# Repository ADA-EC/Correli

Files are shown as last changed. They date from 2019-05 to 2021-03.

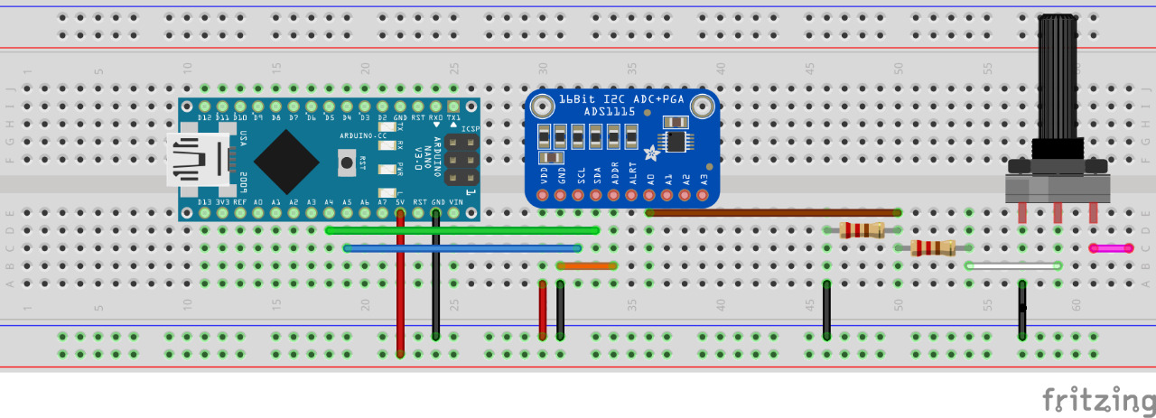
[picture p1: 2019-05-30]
Conversor AD/Esquemático ADC.jpeg

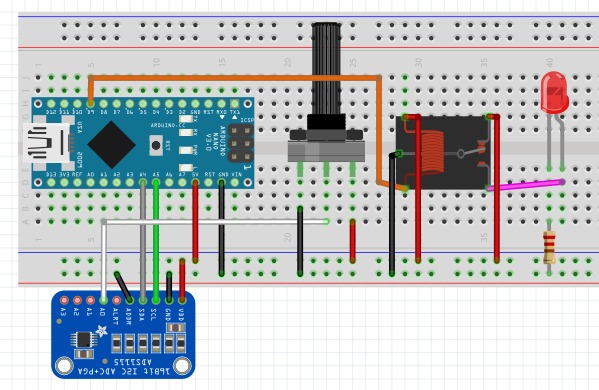
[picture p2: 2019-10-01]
Esquematico/esquematico_nano.jpeg

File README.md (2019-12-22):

# Projeto Correli
Projeto desenvolvido pelo Grupo ADA - Projetos em Engenharia de Computação em parceiria com o Departamento de Estruturas da EESC - USP.

## Configuração
É necessário que um Arduino esteja conectado a uma porta USB do computador para que o código seja executado corretamente.

### Ubuntu
Antes de executar o código no sistesma operacional Ubuntu (os testes foram realizados no Ubuntu 18.04), é necessário possuir o [Python versão 3](https://www.python.org/download/releases/3.0/), e instalar as seguintes bibliotecas:

- [tkinter](https://docs.python.org/3/library/tkinter.html)
- [pyserial](https://pyserial.readthedocs.io/en/latest/pyserial.html) 
- [serial.tools.list_ports](https://pyserial.readthedocs.io/en/latest/tools.html)

Para rodar o código, digitar o seguinte comando no terminal:
   
   `$ python3 interface.py`
 
### Windows
No WIndows, basta rodar o executável previamente criado com Pyinstaller que o programa será executado normalmente. Para executar o código a partir do aquivo Python, é necessário possuir as mesmas bibliotecas e versão do Python exigida para execução em Linux e clicar duas vezes no programa para executá-lo.

## Descrição do Projeto
Criação de um sistema que integre uma prensa hidráulica e uma câmera que tira fotos do corpo de prova que é submetido ao ensaio na prensa. Por meio de uma interface gráfica, o usuário escolhe o modo de operação da camêra (por tempo ou por intervalo de força realizado pela prensa) para tirar a foto. Os dados do ensaio e as tensões nos momentos em que as fotos s
ão tiradas são registrados em um arquivo que fica salvo no final da execução. 

### Prensa Hidráulica
A prensa possui uma saída de tensão que pode ser relacionada com a força que está sendo aplicada em um corpo de prova. Essa tensão pode variar entre -10 volts e 10 volts, a princípio iremos considerar apenas os valores positivos (0-10 volts), tendo uma precisão de 4 casas decimais na leitura dessa tensão e, por fim, podemos convertê-la para força, uma vez que a cada volt temos 25 toneladas sendo aplicado. 

### Câmera
Já a câmera (Canon EOS 30D), possui um função de acionamento remoto, com isso, podemos tirar uma foto sem necessariamente pressionarmos o botão. A ideia do projeto é integrar as fotos tiradas com a força que está sendo aplicada naquele momento e criar um arquivo “.txt”  contendo essa informações. O acionamento da câmera pode ser regulado tanto pelo tempo, tirando fotos em certos intervalos de tempo, quanto por certo intervalos de forças.

### Interface Gráfica
A interface gráfica foi feita em Python. Ela permite que o usuário crie um arquivo com o nome escolhido por ele, escolha a forma de acionamento da câmera (por tempo ou pressão) e defina o intervalo que seja mais conveniente a ele. Então é iniciado o programa, ele se conecta com o código criado para o Arduino Nano e, então, aparece na tela os valores obtidos da pressão que a prensa hidráulica exerce no exato momento em que a foto é tirada. Para utiliza-lá é preciso que o usuário possua tanto o [Python](https://www.python.org/download/releases/3.0/) quanto a biblioteca [PySerial](https://github.com/pyserial/pyserial) instaladas. 

### Prototipagens
O esquemático apresenta o circuito com Arduino, Relé e conversor AD de maneira que seja possível o acionamento da câmera em intervalos especificados pelo usuário de tempo ou tensão.
Simulou-se a prensa para que fosse possível realizar alguns testes. Para isso, utilizou-se 2 potenciômetros conectados, em que um limita a tensão recebida pela fonte (que é de 12V) em até 10V e o segundo simula as tensões que seriam enviadas pela prensa hidráulica.
A câmera é conectada nos terminais do relé indicados no esquemático. Ela tira fotos quando o circuito é fechado pelo relé, em intervalos de tempo ou tensão definidos pelo código.
Imagem do primeiro esquemático

No segundo modelo feito, utilizou-se um Arduino Nano ao invés do Uno. Também não foi necessário utilizar 2 potenciômetros para simular a prensa, apenas 1. Abaixo está o esquemático do segundo modelo.
Imagem do segundo esquemático

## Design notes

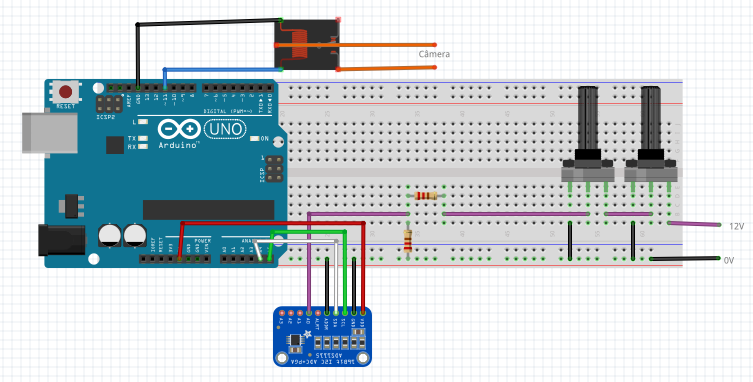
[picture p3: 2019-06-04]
Esquematico/esquematico.png

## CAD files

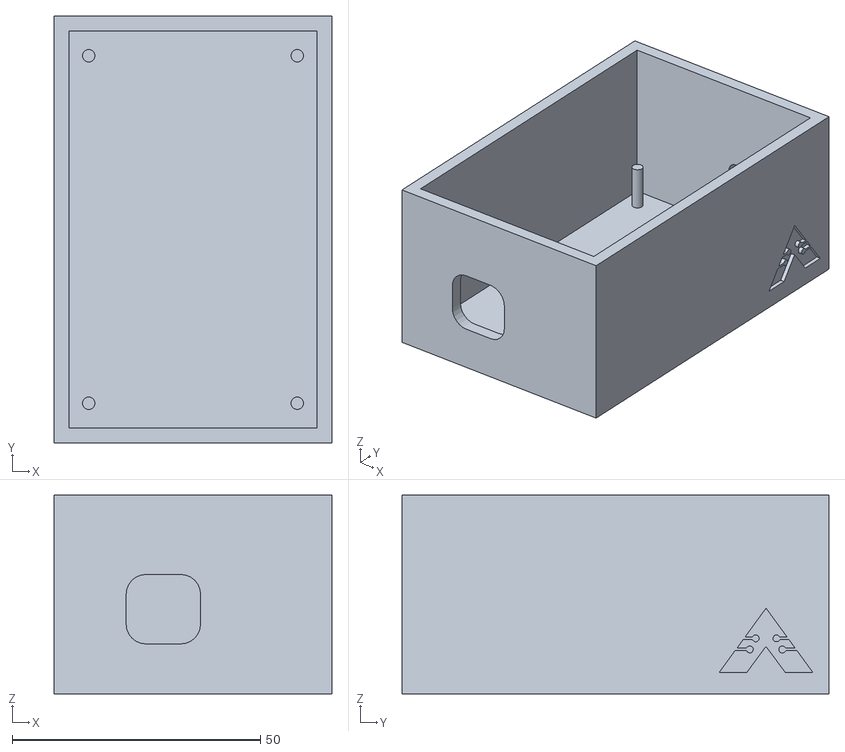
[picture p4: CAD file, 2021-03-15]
Caixa 3D/parede fina.obj
56.0 x 86.0 x 40.0

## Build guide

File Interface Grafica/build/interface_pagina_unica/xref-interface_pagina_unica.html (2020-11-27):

# modulegraph cross reference for interface_pagina_unica.py, pyi_rth__tkinter.py, pyi_rth_multiprocessing.py

interface_pagina_unica.py Script

imports: _bootlocale • _collections_abc • _weakrefset • abc • codecs • collections • collections.abc • copyreg • datetime • encodings • encodings.aliases • encodings.ascii • encodings.base64_codec • encodings.big5 • encodings.big5hkscs • encodings.bz2_codec • encodings.charmap • encodings.cp037 • encodings.cp1006 • encodings.cp1026 • encodings.cp1125 • encodings.cp1140 • encodings.cp1250 • encodings.cp1251 • encodings.cp1252 • encodings.cp1253 • encodings.cp1254 • encodings.cp1255 • encodings.cp1256 • encodings.cp1257 • encodings.cp1258 • encodings.cp273 • encodings.cp424 • encodings.cp437 • encodings.cp500 • encodings.cp720 • encodings.cp737 • encodings.cp775 • encodings.cp850 • encodings.cp852 • encodings.cp855 • encodings.cp856 • encodings.cp857 • encodings.cp858 • encodings.cp860 • encodings.cp861 • encodings.cp862 • encodings.cp863 • encodings.cp864 • encodings.cp865 • encodings.cp866 • encodings.cp869 • encodings.cp874 • encodings.cp875 • encodings.cp932 • encodings.cp949 • encodings.cp950 • encodings.euc_jis_2004 • encodings.euc_jisx0213 • encodings.euc_jp • encodings.euc_kr • encodings.gb18030 • encodings.gb2312 • encodings.gbk • encodings.hex_codec • encodings.hp_roman8 • encodings.hz • encodings.idna • encodings.iso2022_jp • encodings.iso2022_jp_1 • encodings.iso2022_jp_2 • encodings.iso2022_jp_2004 • encodings.iso2022_jp_3 • encodings.iso2022_jp_ext • encodings.iso2022_kr • encodings.iso8859_1 • encodings.iso8859_10 • encodings.iso8859_11 • encodings.iso8859_13 • encodings.iso8859_14 • encodings.iso8859_15 • encodings.iso8859_16 • encodings.iso8859_2 • encodings.iso8859_3 • encodings.iso8859_4 • encodings.iso8859_5 • encodings.iso8859_6 • encodings.iso8859_7 • encodings.iso8859_8 • encodings.iso8859_9 • encodings.johab • encodings.koi8_r • encodings.koi8_t • encodings.koi8_u • encodings.kz1048 • encodings.latin_1 • encodings.mac_arabic • encodings.mac_croatian • encodings.mac_cyrillic • encodings.mac_farsi • encodings.mac_greek • encodings.mac_iceland • encodings.mac_latin2 • encodings.mac_roman • encodings.mac_romanian • encodings.mac_turkish • encodings.mbcs • encodings.oem • encodings.palmos • encodings.ptcp154 • encodings.punycode • encodings.quopri_codec • encodings.raw_unicode_escape • encodings.rot_13 • encodings.shift_jis • encodings.shift_jis_2004 • encodings.shift_jisx0213 • encodings.tis_620 • encodings.undefined • encodings.unicode_escape • encodings.utf_16 • encodings.utf_16_be • encodings.utf_16_le • encodings.utf_32 • encodings.utf_32_be • encodings.utf_32_le • encodings.utf_7 • encodings.utf_8 • encodings.utf_8_sig • encodings.uu_codec • encodings.zlib_codec • enum • functools • heapq • io • json • keyword • linecache • locale • operator • os • pyi_rth__tkinter.py • pyi_rth_multiprocessing.py • re • reprlib • serial • serial.tools.list_ports • sre_compile • sre_constants • sre_parse • sys • tkinter • tkinter.filedialog • tkinter.messagebox • traceback • types • warnings • weakref

pyi_rth__tkinter.py Script

imports: os • sys

imported by: interface_pagina_unica.py

pyi_rth_multiprocessing.py Script

imports: multiprocessing • multiprocessing.popen_fork • multiprocessing.popen_spawn_posix • multiprocessing.popen_spawn_win32 • multiprocessing.spawn • os • re • subprocess • sys

imported by: interface_pagina_unica.py

'System.IO' MissingModule

imported by: serial.serialcli

'java.lang' MissingModule

imported by: platform • xml.sax._exceptions

'org.python' MissingModule

imported by: copy • xml.sax

System MissingModule

imported by: serial.serialcli

__future__ SourceModule

imported by: codeop • doctest • serial • serial.serialcli • serial.serialjava • serial.serialposix • serial.serialutil • serial.serialwin32 • serial.tools.list_ports • serial.tools.list_ports_common • serial.tools.list_ports_linux • serial.tools.list_ports_osx • serial.tools.list_ports_posix • serial.tools.list_ports_windows • serial.win32

_abc (builtin module)

imported by: abc

_aix_support SourceModule

imports: _bootsubprocess • subprocess • sys • sysconfig

imported by: distutils.util • sysconfig

_ast (builtin module)

imported by: ast

_asyncio c:\program files\python39\DLLs\_asyncio.pyd

imported by: asyncio.events • asyncio.futures • asyncio.tasks

_bisect (builtin module)

imported by: bisect

_blake2 (builtin module)

imported by: hashlib

_bootlocale SourceModule

imports: _locale • locale • sys

imported by: interface_pagina_unica.py • locale

_bootsubprocess SourceModule

imports: os

imported by: _aix_support

_bz2 c:\program files\python39\DLLs\_bz2.pyd

imported by: bz2

_codecs (builtin module)

imported by: codecs

_codecs_cn (builtin module)

imported by: encodings.gb18030 • encodings.gb2312 • encodings.gbk • encodings.hz

_codecs_hk (builtin module)

imported by: encodings.big5hkscs

_codecs_iso2022 (builtin module)

imported by: encodings.iso2022_jp • encodings.iso2022_jp_1 • encodings.iso2022_jp_2 • encodings.iso2022_jp_2004 • encodings.iso2022_jp_3 • encodings.iso2022_jp_ext • encodings.iso2022_kr

_codecs_jp (builtin module)

imported by: encodings.cp932 • encodings.euc_jis_2004 • encodings.euc_jisx0213 • encodings.euc_jp • encodings.shift_jis • encodings.shift_jis_2004 • encodings.shift_jisx0213

_codecs_kr (builtin module)

imported by: encodings.cp949 • encodings.euc_kr • encodings.johab

_codecs_tw (builtin module)

imported by: encodings.big5 • encodings.cp950

_collections (builtin module)

imported by: collections • threading

_collections_abc SourceModule

imports: abc • sys

imported by: collections • collections.abc • contextlib • interface_pagina_unica.py • locale • os • pathlib • random • types • weakref

_compat_pickle SourceModule

imported by: _pickle • pickle

_compression SourceModule

imports: io

imported by: bz2 • gzip • lzma

_contextvars (builtin module)

imported by: contextvars

_csv (builtin module)

imported by: csv

_ctypes c:\program files\python39\DLLs\_ctypes.pyd

imported by: ctypes

_datetime (builtin module)

imports: _strptime • time

imported by: datetime

_decimal c:\program files\python39\DLLs\_decimal.pyd

imported by: decimal

_elementtree c:\program files\python39\DLLs\_elementtree.pyd

imports: pyexpat • xml.etree.ElementInclude • xml.etree.ElementPath • xml.etree.ElementTree • xml.etree.cElementTree

imported by: xml.etree.ElementTree

_frozen_importlib ExcludedModule

imported by: importlib • importlib.abc • zipimport

_frozen_importlib_external MissingModule

imported by: importlib • importlib._bootstrap • importlib.abc • zipimport

_functools (builtin module)

imported by: functools

_hashlib c:\program files\python39\DLLs\_hashlib.pyd

imported by: hashlib • hmac

_heapq (builtin module)

imported by: heapq

_imp (builtin module)

imported by: distutils.sysconfig • importlib • importlib.machinery • importlib.util • zipimport

_io (builtin module)

imported by: io • zipimport

_json (builtin module)

imports: json.decoder

imported by: json.decoder • json.encoder • json.scanner

_locale (builtin module)

imported by: _bootlocale • locale • re

_lzma c:\program files\python39\DLLs\_lzma.pyd

imported by: lzma

_md5 (builtin module)

imported by: hashlib

_multibytecodec (builtin module)

imported by: encodings.big5 • encodings.big5hkscs • encodings.cp932 • encodings.cp949 • encodings.cp950 • encodings.euc_jis_2004 • encodings.euc_jisx0213 • encodings.euc_jp • encodings.euc_kr • encodings.gb18030 • encodings.gb2312 • encodings.gbk • encodings.hz • encodings.iso2022_jp • encodings.iso2022_jp_1 • encodings.iso2022_jp_2 • encodings.iso2022_jp_2004 • encodings.iso2022_jp_3 • encodings.iso2022_jp_ext • encodings.iso2022_kr • encodings.johab • encodings.shift_jis • encodings.shift_jis_2004 • encodings.shift_jisx0213

_multiprocessing c:\program files\python39\DLLs\_multiprocessing.pyd

imported by: multiprocessing.connection • multiprocessing.queues • multiprocessing.resource_tracker • multiprocessing.synchronize

_opcode (builtin module)

imported by: opcode

_operator (builtin module)

imported by: hmac • operator

_osx_support SourceModule

imports: contextlib • distutils • distutils.log • os • re • sys • tempfile

imported by: distutils.sysconfig • distutils.util • sysconfig

_overlapped c:\program files\python39\DLLs\_overlapped.pyd

imported by: asyncio.windows_events

_pickle (builtin module)

imports: _compat_pickle • codecs • copyreg

imported by: pickle

_posixshmem MissingModule

imported by: multiprocessing.resource_tracker • multiprocessing.shared_memory

_posixsubprocess MissingModule

imports: gc

imported by: multiprocessing.util • subprocess

_py_abc SourceModule

imports: _weakrefset

imported by: abc

_pydecimal SourceModule

imports: collections • contextvars • itertools • locale • math • numbers • re • sys

imported by: decimal

_queue c:\program files\python39\DLLs\_queue.pyd

imported by: queue

_random (builtin module)

imported by: random

_scproxy MissingModule

imported by: urllib.request

_sha1 (builtin module)

imported by: hashlib

_sha256 (builtin module)

imported by: hashlib

_sha3 (builtin module)

imported by: hashlib

_sha512 (builtin module)

imported by: hashlib • random

_signal (builtin module)

imported by: signal

_socket c:\program files\python39\DLLs\_socket.pyd

imported by: socket

_sre (builtin module)

imports: copy • re

imported by: sre_compile • sre_constants

_ssl c:\program files\python39\DLLs\_ssl.pyd

imports: socket

imported by: ssl

_stat (builtin module)

imported by: stat

_statistics (builtin module)

imported by: statistics

_string (builtin module)

imported by: string

_strptime SourceModule

imports: _thread • calendar • datetime • locale • re • time

imported by: _datetime • datetime • time

_struct (builtin module)

imported by: struct

_thread (builtin module)

imported by: _strptime • functools • reprlib • tempfile • test.support • threading

_threading_local SourceModule

imports: contextlib • threading • weakref

imported by: threading

_tkinter c:\program files\python39\DLLs\_tkinter.pyd

imported by: tkinter

_tracemalloc (builtin module)

imported by: tracemalloc

_warnings (builtin module)

imported by: warnings

_weakref (builtin module)

imported by: _weakrefset • collections • weakref • xml.sax.expatreader

_weakrefset SourceModule

imports: _weakref • types

imported by: _py_abc • interface_pagina_unica.py • multiprocessing.process • threading • weakref

_winapi (builtin module)

imported by: asyncio.windows_events • asyncio.windows_utils • encodings • multiprocessing.connection • multiprocessing.heap • multiprocessing.popen_spawn_win32 • multiprocessing.reduction • multiprocessing.shared_memory • multiprocessing.spawn • subprocess • test.support

_winreg MissingModule

imported by: platform

abc SourceModule

imports: _abc • _py_abc

imported by: _collections_abc • contextlib • email._policybase • functools • importlib.abc • importlib.metadata • inspect • interface_pagina_unica.py • io • multiprocessing.reduction • numbers • os • selectors • typing

argparse SourceModule

imports: copy • gettext • os • re • shutil • sys • textwrap • warnings

imported by: ast • calendar • code • dis • doctest • gzip • http.server • inspect • serial.tools.list_ports • tarfile • tokenize • unittest.main • zipfile

array (builtin module)

imported by: multiprocessing.dummy • multiprocessing.managers • multiprocessing.reduction • serial.serialposix • serial.serialutil • socket

ast SourceModule

imports: _ast • argparse • collections • contextlib • enum • inspect • sys • warnings

imported by: inspect

asyncio Package

imports: asyncio • asyncio.DefaultEventLoopPolicy • asyncio.base_events • asyncio.base_futures • asyncio.base_subprocess • asyncio.base_tasks • asyncio.constants • asyncio.coroutines • asyncio.events • asyncio.exceptions • asyncio.format_helpers • asyncio.futures • asyncio.locks • asyncio.proactor_events • asyncio.protocols • asyncio.queues • asyncio.runners • asyncio.selector_events • asyncio.sslproto • asyncio.staggered • asyncio.streams • asyncio.subprocess • asyncio.tasks • asyncio.threads • asyncio.transports • asyncio.trsock • asyncio.unix_events • asyncio.windows_events • asyncio.windows_utils • sys

imported by: asyncio • asyncio.base_events • asyncio.base_futures • asyncio.base_subprocess • asyncio.base_tasks • asyncio.constants • asyncio.coroutines • asyncio.events • asyncio.exceptions • asyncio.format_helpers • asyncio.futures • asyncio.locks • asyncio.log • asyncio.proactor_events • asyncio.protocols • asyncio.queues • asyncio.runners • asyncio.selector_events • asyncio.sslproto • asyncio.staggered • asyncio.streams • asyncio.subprocess • asyncio.tasks • asyncio.threads • asyncio.transports • asyncio.trsock • asyncio.unix_events • asyncio.windows_events • asyncio.windows_utils • unittest.async_case

asyncio.DefaultEventLoopPolicy MissingModule

imported by: asyncio • asyncio.events

asyncio.base_events SourceModule

imports: asyncio • asyncio.constants • asyncio.coroutines • asyncio.events • asyncio.exceptions • asyncio.futures • asyncio.log • asyncio.protocols • asyncio.sslproto • asyncio.staggered • asyncio.tasks • asyncio.transports • asyncio.trsock • collections • collections.abc • concurrent.futures • functools • heapq • itertools • os • socket • ssl • stat • subprocess • sys • threading • time • traceback • warnings • weakref

imported by: asyncio • asyncio.proactor_events • asyncio.selector_events • asyncio.unix_events

asyncio.base_futures SourceModule

imports: asyncio • asyncio.format_helpers • reprlib

imported by: asyncio • asyncio.base_tasks • asyncio.coroutines • asyncio.futures

asyncio.base_subprocess SourceModule

imports: asyncio • asyncio.log • asyncio.protocols • asyncio.transports • collections • subprocess • warnings

imported by: asyncio • asyncio.unix_events • asyncio.windows_events

asyncio.base_tasks SourceModule

imports: asyncio • asyncio.base_futures • asyncio.coroutines • linecache • traceback

imported by: asyncio • asyncio.tasks

asyncio.constants SourceModule

imports: asyncio • enum

imported by: asyncio • asyncio.base_events • asyncio.coroutines • asyncio.format_helpers • asyncio.proactor_events • asyncio.selector_events • asyncio.sslproto • asyncio.unix_events

asyncio.coroutines SourceModule

imports: asyncio • asyncio.base_futures • asyncio.constants • asyncio.format_helpers • asyncio.log • collections.abc • functools • inspect • os • sys • traceback • types • warnings

imported by: asyncio • asyncio.base_events • asyncio.base_tasks • asyncio.runners • asyncio.streams • asyncio.tasks • asyncio.unix_events

asyncio.events SourceModule

imports: _asyncio • asyncio • asyncio.DefaultEventLoopPolicy • asyncio.format_helpers • contextvars • os • socket • subprocess • sys • threading

imported by: asyncio • asyncio.base_events • asyncio.futures • asyncio.locks • asyncio.queues • asyncio.runners • asyncio.selector_events • asyncio.staggered • asyncio.streams • asyncio.subprocess • asyncio.tasks • asyncio.threads • asyncio.unix_events • asyncio.windows_events • test.support

asyncio.exceptions SourceModule

imports: asyncio

imported by: asyncio • asyncio.base_events • asyncio.futures • asyncio.locks • asyncio.proactor_events • asyncio.staggered • asyncio.streams • asyncio.tasks • asyncio.unix_events • asyncio.windows_events

asyncio.format_helpers SourceModule

imports: asyncio • asyncio.constants • functools • inspect • reprlib • sys • traceback

imported by: asyncio • asyncio.base_futures • asyncio.coroutines • asyncio.events • asyncio.futures • asyncio.streams

asyncio.futures SourceModule

imports: _asyncio • asyncio • asyncio.base_futures • asyncio.events • asyncio.exceptions • asyncio.format_helpers • concurrent.futures • contextvars • logging • sys

imported by: asyncio • asyncio.base_events • asyncio.proactor_events • asyncio.selector_events • asyncio.tasks • asyncio.unix_events • asyncio.windows_events

asyncio.locks SourceModule

imports: asyncio • asyncio.events • asyncio.exceptions • collections • warnings

imported by: asyncio • asyncio.queues • asyncio.staggered

asyncio.log SourceModule

imports: asyncio • logging

imported by: asyncio.base_events • asyncio.base_subprocess • asyncio.coroutines • asyncio.proactor_events • asyncio.selector_events • asyncio.sslproto • asyncio.streams • asyncio.subprocess • asyncio.unix_events • asyncio.windows_events

asyncio.proactor_events SourceModule

imports: asyncio • asyncio.base_events • asyncio.constants • asyncio.exceptions • asyncio.futures • asyncio.log • asyncio.protocols • asyncio.sslproto • asyncio.transports • asyncio.trsock • collections • io • os • signal • socket • threading • warnings

imported by: asyncio • asyncio.windows_events

asyncio.protocols SourceModule

imports: asyncio

imported by: asyncio • asyncio.base_events • asyncio.base_subprocess • asyncio.proactor_events • asyncio.selector_events • asyncio.sslproto • asyncio.streams • asyncio.subprocess

asyncio.queues SourceModule

imports: asyncio • asyncio.events • asyncio.locks • collections • heapq • warnings

imported by: asyncio • asyncio.tasks

asyncio.runners SourceModule

imports: asyncio • asyncio.coroutines • asyncio.events • asyncio.tasks

imported by: asyncio

asyncio.selector_events SourceModule

imports: asyncio • asyncio.base_events • asyncio.constants • asyncio.events • asyncio.futures • asyncio.log • asyncio.protocols • asyncio.sslproto • asyncio.transports • asyncio.trsock • collections • errno • functools • selectors • socket • ssl • warnings • weakref

imported by: asyncio • asyncio.unix_events • asyncio.windows_events

asyncio.sslproto SourceModule

imports: asyncio • asyncio.constants • asyncio.log • asyncio.protocols • asyncio.transports • collections • ssl • warnings

imported by: asyncio • asyncio.base_events • asyncio.proactor_events • asyncio.selector_events

asyncio.staggered SourceModule

imports: asyncio • asyncio.events • asyncio.exceptions • asyncio.locks • asyncio.tasks • contextlib • typing

imported by: asyncio • asyncio.base_events

asyncio.streams SourceModule

imports: asyncio • asyncio.coroutines • asyncio.events • asyncio.exceptions • asyncio.format_helpers • asyncio.log • asyncio.protocols • asyncio.tasks • socket • sys • warnings • weakref

imported by: asyncio • asyncio.subprocess

asyncio.subprocess SourceModule

imports: asyncio • asyncio.events • asyncio.log • asyncio.protocols • asyncio.streams • asyncio.tasks • subprocess • warnings

imported by: asyncio

asyncio.tasks SourceModule

imports: _asyncio • asyncio • asyncio.base_tasks • asyncio.coroutines • asyncio.events • asyncio.exceptions • asyncio.futures • asyncio.queues • concurrent.futures • contextvars • functools • inspect • itertools • types • warnings • weakref

imported by: asyncio • asyncio.base_events • asyncio.runners • asyncio.staggered • asyncio.streams • asyncio.subprocess • asyncio.unix_events • asyncio.windows_events

asyncio.threads SourceModule

imports: asyncio • asyncio.events • contextvars • functools

imported by: asyncio

asyncio.transports SourceModule

imports: asyncio

imported by: asyncio • asyncio.base_events • asyncio.base_subprocess • asyncio.proactor_events • asyncio.selector_events • asyncio.sslproto • asyncio.unix_events

asyncio.trsock SourceModule

imports: asyncio • socket • warnings

imported by: asyncio • asyncio.base_events • asyncio.proactor_events • asyncio.selector_events

asyncio.unix_events SourceModule

imports: asyncio • asyncio.base_events • asyncio.base_subprocess • asyncio.constants • asyncio.coroutines • asyncio.events • asyncio.exceptions • asyncio.futures • asyncio.log • asyncio.selector_events • asyncio.tasks • asyncio.transports • errno • io • itertools • os • selectors • signal • socket • stat • subprocess • sys • threading • warnings

imported by: asyncio

asyncio.windows_events SourceModule

imports: _overlapped • _winapi • asyncio • asyncio.base_subprocess • asyncio.events • asyncio.exceptions • asyncio.futures • asyncio.log • asyncio.proactor_events • asyncio.selector_events • asyncio.tasks • asyncio.windows_utils • errno • math • msvcrt • socket • struct • time • weakref

imported by: asyncio

asyncio.windows_utils SourceModule

imports: _winapi • asyncio • itertools • msvcrt • os • subprocess • sys • tempfile • warnings

imported by: asyncio • asyncio.windows_events

atexit (builtin module)

imported by: logging • multiprocessing.util • weakref

base64 SourceModule

imports: binascii • getopt • re • struct • sys

imported by: email._encoded_words • email.base64mime • email.encoders • encodings.base64_codec • http.server • secrets • ssl • urllib.request • xmlrpc.client

bdb SourceModule

imports: fnmatch • inspect • linecache • os • reprlib • sys

imported by: pdb

binascii (builtin module)

imported by: base64 • email._encoded_words • email.base64mime • email.contentmanager • email.header • encodings.hex_codec • encodings.uu_codec • http.server • plistlib • quopri • secrets • uu • zipfile

bisect SourceModule

imports: _bisect

imported by: multiprocessing.heap • random • statistics • urllib.request

builtins (builtin module)

imported by: bz2 • codecs • doctest • gettext • gzip • inspect • locale • lzma • operator • pydoc • reprlib • subprocess • tarfile • tokenize • warnings

bz2 SourceModule

imports: _bz2 • _compression • builtins • io • os • threading

imported by: encodings.bz2_codec • shutil • tarfile • test.support • zipfile

calendar SourceModule

imports: argparse • datetime • itertools • locale • sys

imported by: _strptime • email._parseaddr • http.cookiejar • ssl

cmd SourceModule

imports: readline • string • sys

imported by: pdb

code SourceModule

imports: argparse • codeop • readline • sys • traceback

imported by: pdb

codecs SourceModule

imports: _codecs • builtins • encodings • sys

imported by: _pickle • encodings • encodings.ascii • encodings.base64_codec • encodings.big5 • encodings.big5hkscs • encodings.bz2_codec • encodings.charmap • encodings.cp037 • encodings.cp1006 • encodings.cp1026 • encodings.cp1125 • encodings.cp1140 • encodings.cp1250 • encodings.cp1251 • encodings.cp1252 • encodings.cp1253 • encodings.cp1254 • encodings.cp1255 • encodings.cp1256 • encodings.cp1257 • encodings.cp1258 • encodings.cp273 • encodings.cp424 • encodings.cp437 • encodings.cp500 • encodings.cp720 • encodings.cp737 • encodings.cp775 • encodings.cp850 • encodings.cp852 • encodings.cp855 • encodings.cp856 • encodings.cp857 • encodings.cp858 • encodings.cp860 • encodings.cp861 • encodings.cp862 • encodings.cp863 • encodings.cp864 • encodings.cp865 • encodings.cp866 • encodings.cp869 • encodings.cp874 • encodings.cp875 • encodings.cp932 • encodings.cp949 • encodings.cp950 • encodings.euc_jis_2004 • encodings.euc_jisx0213 • encodings.euc_jp • encodings.euc_kr • encodings.gb18030 • encodings.gb2312 • encodings.gbk • encodings.hex_codec • encodings.hp_roman8 • encodings.hz • encodings.idna • encodings.iso2022_jp • encodings.iso2022_jp_1 • encodings.iso2022_jp_2 • encodings.iso2022_jp_2004 • encodings.iso2022_jp_3 • encodings.iso2022_jp_ext • encodings.iso2022_kr • encodings.iso8859_1 • encodings.iso8859_10 • encodings.iso8859_11 • encodings.iso8859_13 • encodings.iso8859_14 • encodings.iso8859_15 • encodings.iso8859_16 • encodings.iso8859_2 • encodings.iso8859_3 • encodings.iso8859_4 • encodings.iso8859_5 • encodings.iso8859_6 • encodings.iso8859_7 • encodings.iso8859_8 • encodings.iso8859_9 • encodings.johab • encodings.koi8_r • encodings.koi8_t • encodings.koi8_u • encodings.kz1048 • encodings.latin_1 • encodings.mac_arabic • encodings.mac_croatian • encodings.mac_cyrillic • encodings.mac_farsi • encodings.mac_greek • encodings.mac_iceland • encodings.mac_latin2 • encodings.mac_roman • encodings.mac_romanian • encodings.mac_turkish • encodings.mbcs • encodings.oem • encodings.palmos • encodings.ptcp154 • encodings.punycode • encodings.quopri_codec • encodings.raw_unicode_escape • encodings.rot_13 • encodings.shift_jis • encodings.shift_jis_2004 • encodings.shift_jisx0213 • encodings.tis_620 • encodings.undefined • encodings.unicode_escape • encodings.utf_16 • encodings.utf_16_be • encodings.utf_16_le • encodings.utf_32 • encodings.utf_32_be • encodings.utf_32_le • encodings.utf_7 • encodings.utf_8 • encodings.utf_8_sig • encodings.uu_codec • encodings.zlib_codec • interface_pagina_unica.py • json • lib2to3.pgen2.tokenize • pickle • plistlib • tokenize • xml.sax.saxutils

codeop SourceModule

imports: __future__ • warnings

imported by: code

collections Package

imports: _collections • _collections_abc • _weakref • copy • heapq • itertools • keyword • operator • reprlib • sys • warnings

imported by: _pydecimal • ast • asyncio.base_events • asyncio.base_subprocess • asyncio.locks • asyncio.proactor_events • asyncio.queues • asyncio.selector_events • asyncio.sslproto • collections.abc • concurrent.futures._base • configparser • contextlib • difflib • dis • doctest • email.feedparser • functools • importlib.metadata • inspect • interface_pagina_unica.py • lib2to3.btm_matcher • lib2to3.refactor • multiprocessing.heap • multiprocessing.pool • multiprocessing.queues • pkgutil • platform • pprint • pydoc • queue • selectors • shlex • shutil • ssl • statistics • string • threading • tokenize • traceback • typing • unittest._log • unittest.case • unittest.util • urllib.parse • xml.etree.ElementTree

collections.abc SourceModule

imports: _collections_abc • collections

imported by: asyncio.base_events • asyncio.coroutines • configparser • http.client • inspect • interface_pagina_unica.py • logging • selectors • test.support • tracemalloc • typing • xml.etree.ElementTree

concurrent Package

imported by: concurrent.futures

concurrent.futures Package

imports: concurrent • concurrent.futures._base • concurrent.futures.process • concurrent.futures.thread

imported by: asyncio.base_events • asyncio.futures • asyncio.tasks • concurrent.futures._base • concurrent.futures.process • concurrent.futures.thread

concurrent.futures._base SourceModule

imports: collections • concurrent.futures • logging • threading • time • types

imported by: concurrent.futures • concurrent.futures.process • concurrent.futures.thread

concurrent.futures.process SourceModule

imports: concurrent.futures • concurrent.futures._base • functools • itertools • multiprocessing • multiprocessing.connection • multiprocessing.queues • os • queue • sys • threading • traceback • weakref

imported by: concurrent.futures

concurrent.futures.thread SourceModule

imports: concurrent.futures • concurrent.futures._base • itertools • os • queue • threading • types • weakref

imported by: concurrent.futures

configparser SourceModule

imports: collections • collections.abc • functools • io • itertools • os • re • sys • warnings

imported by: importlib.metadata

contextlib SourceModule

imports: _collections_abc • abc • collections • functools • sys • types

imported by: _osx_support • _threading_local • ast • asyncio.staggered • getpass • http.server • importlib.metadata • importlib.util • subprocess • test.support • typing • unittest.case • urllib.request • xml.etree.ElementTree • zipfile

contextvars SourceModule

imports: _contextvars

imported by: _pydecimal • asyncio.events • asyncio.futures • asyncio.tasks • asyncio.threads

copy SourceModule

imports: 'org.python' • copyreg • types • weakref

imported by: _sre • argparse • collections • email.generator • gettext • http.cookiejar • http.server • tarfile • weakref • webbrowser • xml.etree.ElementInclude

copyreg SourceModule

imported by: _pickle • copy • interface_pagina_unica.py • multiprocessing.reduction • pickle • re

csv SourceModule

imports: _csv • io • re

imported by: importlib.metadata

ctypes Package

imports: _ctypes • ctypes._endian • nt • os • struct • sys • types

imported by: ctypes._aix • ctypes._endian • ctypes.macholib • ctypes.util • ctypes.wintypes • multiprocessing.sharedctypes • serial.serialwin32 • serial.tools.list_ports_osx • serial.tools.list_ports_windows • serial.win32 • test.support

ctypes._endian SourceModule

imports: ctypes • sys

imported by: ctypes

ctypes.wintypes SourceModule

imports: ctypes

imported by: serial.tools.list_ports_windows • serial.win32 • test.support

datetime SourceModule

imports: _datetime • _strptime • math • sys • time • warnings

imported by: _strptime • calendar • email.utils • http.cookiejar • http.server • interface_pagina_unica.py • plistlib • test.support.testresult • xmlrpc.client

decimal SourceModule

imports: _decimal • _pydecimal

imported by: fractions • statistics • test.support • xmlrpc.client

difflib SourceModule

imports: collections • difflib • heapq • re • types

imported by: difflib • doctest • unittest.case

dis SourceModule

imports: argparse • collections • io • opcode • sys • types

imported by: inspect • pdb

distutils Package

imports: distutils.ccompiler • distutils.log • distutils.sysconfig • sys

imported by: _osx_support • distutils.ccompiler • distutils.debug • distutils.dep_util • distutils.dir_util • distutils.errors • distutils.fancy_getopt • distutils.file_util • distutils.filelist • distutils.log • distutils.spawn • distutils.sysconfig • distutils.text_file • distutils.util • test.support

distutils.ccompiler SourceModule

imports: distutils • distutils.debug • distutils.dep_util • distutils.dir_util • distutils.errors • distutils.fancy_getopt • distutils.file_util • distutils.log • distutils.spawn • distutils.util • os • re • sys • tempfile

imported by: distutils • test.support

distutils.debug SourceModule

imports: distutils • os

imported by: distutils.ccompiler • distutils.filelist • distutils.spawn

distutils.dep_util SourceModule

imports: distutils • distutils.errors • os • stat

imported by: distutils.ccompiler • distutils.file_util • distutils.util

distutils.dir_util SourceModule

imports: distutils • distutils.errors • distutils.file_util • distutils.log • errno • os

imported by: distutils.ccompiler • distutils.util

distutils.errors SourceModule

imports: distutils

imported by: distutils.ccompiler • distutils.dep_util • distutils.dir_util • distutils.fancy_getopt • distutils.file_util • distutils.filelist • distutils.spawn • distutils.sysconfig • distutils.util • test.support

distutils.fancy_getopt SourceModule

imports: distutils • distutils.errors • getopt • re • string • sys

imported by: distutils.ccompiler

distutils.file_util SourceModule

imports: distutils • distutils.dep_util • distutils.errors • distutils.log • errno • ntpath • os • stat

imported by: distutils.ccompiler • distutils.dir_util • distutils.util

distutils.filelist SourceModule

imports: distutils • distutils.debug • distutils.errors • distutils.log • distutils.util • fnmatch • functools • os • re

imported by: distutils.util

distutils.log SourceModule

imports: distutils • sys

imported by: _osx_support • distutils • distutils.ccompiler • distutils.dir_util • distutils.file_util • distutils.filelist • distutils.spawn • distutils.util

distutils.spawn SourceModule

imports: distutils • distutils.debug • distutils.errors • distutils.log • distutils.sysconfig • os • subprocess • sys

imported by: distutils.ccompiler • distutils.util • test.support

distutils.sysconfig SourceModule

imports: _imp • _osx_support • distutils • distutils.errors • distutils.text_file • os • re • sys • warnings

imported by: distutils • distutils.spawn • distutils.util • test.support

distutils.text_file SourceModule

imports: distutils • io • sys

imported by: distutils.sysconfig

distutils.util SourceModule

imports: _aix_support • _osx_support • distutils • distutils.dep_util • distutils.dir_util • distutils.errors • distutils.file_util • distutils.filelist • distutils.log • distutils.spawn • distutils.sysconfig • importlib.util • os • pwd • py_compile • re • string • subprocess • sys • tempfile

imported by: distutils.ccompiler • distutils.filelist

doctest SourceModule

imports: __future__ • argparse • builtins • collections • difflib • inspect • io • linecache • os • pdb • re • sys • traceback • unittest

imported by: pickle • test.support

email Package

imports: email._header_value_parser • email.charset • email.errors • email.header • email.parser

imported by: email._encoded_words • email._header_value_parser • email._parseaddr • email._policybase • email.base64mime • email.charset • email.contentmanager • email.encoders • email.errors • email.feedparser • email.generator • email.header • email.headerregistry • email.iterators • email.message • email.parser • email.policy • email.quoprimime • email.utils • importlib.metadata • urllib.request

email._encoded_words SourceModule

imports: base64 • binascii • email • email.errors • functools • re • string

imported by: email._header_value_parser • email.message

email._header_value_parser SourceModule

imports: email • email._encoded_words • email.errors • email.utils • operator • re • string • sys • urllib

imported by: email • email.headerregistry

email._parseaddr SourceModule

imports: calendar • email • time

imported by: email.utils

email._policybase SourceModule

imports: abc • email • email.charset • email.header • email.utils

imported by: email.feedparser • email.message • email.parser • email.policy

email.base64mime SourceModule

imports: base64 • binascii • email

imported by: email.charset • email.header

email.charset SourceModule

imports: email • email.base64mime • email.encoders • email.errors • email.quoprimime • functools

imported by: email • email._policybase • email.contentmanager • email.header • email.message • email.utils

email.contentmanager SourceModule

imports: binascii • email • email.charset • email.errors • email.message • email.quoprimime

imported by: email.policy

email.encoders SourceModule

imports: base64 • email • quopri

imported by: email.charset

email.errors SourceModule

imports: email

imported by: email • email._encoded_words • email._header_value_parser • email.charset • email.contentmanager • email.feedparser • email.header • email.headerregistry • email.message

email.feedparser SourceModule

imports: collections • email • email._policybase • email.errors • email.message • io • re

imported by: email.parser

email.generator SourceModule

imports: copy • email • email.utils • io • random • re • sys • time

imported by: email.message

email.header SourceModule

imports: binascii • email • email.base64mime • email.charset • email.errors • email.quoprimime • re

imported by: email • email._policybase

email.headerregistry SourceModule

imports: email • email._header_value_parser • email.errors • email.utils • types

imported by: email.policy

email.iterators SourceModule

imports: email • io • sys

imported by: email.message

email.message SourceModule

imports: email • email._encoded_words • email._policybase • email.charset • email.errors • email.generator • email.iterators • email.policy • email.utils • io • quopri • re • uu

imported by: email.contentmanager • email.feedparser • email.policy • http.client • pydoc

email.parser SourceModule

imports: email • email._policybase • email.feedparser • io

imported by: email • http.client

email.policy SourceModule

imports: email • email._policybase • email.contentmanager • email.headerregistry • email.message • email.utils • re • sys

imported by: email.message

email.quoprimime SourceModule

imports: email • re • string

imported by: email.charset • email.contentmanager • email.header

email.utils SourceModule

imports: datetime • email • email._parseaddr • email.charset • os • random • re • socket • time • urllib.parse

imported by: email._header_value_parser • email._policybase • email.generator • email.headerregistry • email.message • email.policy • http.server • urllib.request

encodings Package

imports: _winapi • codecs • encodings • encodings.aliases • encodings.ascii • encodings.base64_codec • encodings.big5 • encodings.big5hkscs • encodings.bz2_codec • encodings.charmap • encodings.cp037 • encodings.cp1006 • encodings.cp1026 • encodings.cp1125 • encodings.cp1140 • encodings.cp1250 • encodings.cp1251 • encodings.cp1252 • encodings.cp1253 • encodings.cp1254 • encodings.cp1255 • encodings.cp1256 • encodings.cp1257 • encodings.cp1258 • encodings.cp273 • encodings.cp424 • encodings.cp437 • encodings.cp500 • encodings.cp720 • encodings.cp737 • encodings.cp775 • encodings.cp850 • encodings.cp852 • encodings.cp855 • encodings.cp856 • encodings.cp857 • encodings.cp858 • encodings.cp860 • encodings.cp861 • encodings.cp862 • encodings.cp863 • encodings.cp864 • encodings.cp865 • encodings.cp866 • encodings.cp869 • encodings.cp874 • encodings.cp875 • encodings.cp932 • encodings.cp949 • encodings.cp950 • encodings.euc_jis_2004 • encodings.euc_jisx0213 • encodings.euc_jp • encodings.euc_kr • encodings.gb18030 • encodings.gb2312 • encodings.gbk • encodings.hex_codec • encodings.hp_roman8 • encodings.hz • encodings.idna • encodings.iso2022_jp • encodings.iso2022_jp_1 • encodings.iso2022_jp_2 • encodings.iso2022_jp_2004 • encodings.iso2022_jp_3 • encodings.iso2022_jp_ext • encodings.iso2022_kr • encodings.iso8859_1 • encodings.iso8859_10 • encodings.iso8859_11 • encodings.iso8859_13 • encodings.iso8859_14 • encodings.iso8859_15 • encodings.iso8859_16 • encodings.iso8859_2 • encodings.iso8859_3 • encodings.iso8859_4 • encodings.iso8859_5 • encodings.iso8859_6 • encodings.iso8859_7 • encodings.iso8859_8 • encodings.iso8859_9 • encodings.johab • encodings.koi8_r • encodings.koi8_t • encodings.koi8_u • encodings.kz1048 • encodings.latin_1 • encodings.mac_arabic • encodings.mac_croatian • encodings.mac_cyrillic • encodings.mac_farsi • encodings.mac_greek • encodings.mac_iceland • encodings.mac_latin2 • encodings.mac_roman • encodings.mac_romanian • encodings.mac_turkish • encodings.mbcs • encodings.oem • encodings.palmos • encodings.ptcp154 • encodings.punycode • encodings.quopri_codec • encodings.raw_unicode_escape • encodings.rot_13 • encodings.shift_jis • encodings.shift_jis_2004 • encodings.shift_jisx0213 • encodings.tis_620 • encodings.undefined • encodings.unicode_escape • encodings.utf_16 • encodings.utf_16_be • encodings.utf_16_le • encodings.utf_32 • encodings.utf_32_be • encodings.utf_32_le • encodings.utf_7 • encodings.utf_8 • encodings.utf_8_sig • encodings.uu_codec • encodings.zlib_codec • sys

imported by: codecs • encodings • encodings.aliases • encodings.ascii • encodings.base64_codec • encodings.big5 • encodings.big5hkscs • encodings.bz2_codec • encodings.charmap • encodings.cp037 • encodings.cp1006 • encodings.cp1026 • encodings.cp1125 • encodings.cp1140 • encodings.cp1250 • encodings.cp1251 • encodings.cp1252 • encodings.cp1253 • encodings.cp1254 • encodings.cp1255 • encodings.cp1256 • encodings.cp1257 • encodings.cp1258 • encodings.cp273 • encodings.cp424 • encodings.cp437 • encodings.cp500 • encodings.cp720 • encodings.cp737 • encodings.cp775 • encodings.cp850 • encodings.cp852 • encodings.cp855 • encodings.cp856 • encodings.cp857 • encodings.cp858 • encodings.cp860 • encodings.cp861 • encodings.cp862 • encodings.cp863 • encodings.cp864 • encodings.cp865 • encodings.cp866 • encodings.cp869 • encodings.cp874 • encodings.cp875 • encodings.cp932 • encodings.cp949 • encodings.cp950 • encodings.euc_jis_2004 • encodings.euc_jisx0213 • encodings.euc_jp • encodings.euc_kr • encodings.gb18030 • encodings.gb2312 • encodings.gbk • encodings.hex_codec • encodings.hp_roman8 • encodings.hz • encodings.idna • encodings.iso2022_jp • encodings.iso2022_jp_1 • encodings.iso2022_jp_2 • encodings.iso2022_jp_2004 • encodings.iso2022_jp_3 • encodings.iso2022_jp_ext • encodings.iso2022_kr • encodings.iso8859_1 • encodings.iso8859_10 • encodings.iso8859_11 • encodings.iso8859_13 • encodings.iso8859_14 • encodings.iso8859_15 • encodings.iso8859_16 • encodings.iso8859_2 • encodings.iso8859_3 • encodings.iso8859_4 • encodings.iso8859_5 • encodings.iso8859_6 • encodings.iso8859_7 • encodings.iso8859_8 • encodings.iso8859_9 • encodings.johab • encodings.koi8_r • encodings.koi8_t • encodings.koi8_u • encodings.kz1048 • encodings.latin_1 • encodings.mac_arabic • encodings.mac_croatian • encodings.mac_cyrillic • encodings.mac_farsi • encodings.mac_greek • encodings.mac_iceland • encodings.mac_latin2 • encodings.mac_roman • encodings.mac_romanian • encodings.mac_turkish • encodings.mbcs • encodings.oem • encodings.palmos • encodings.ptcp154 • encodings.punycode • encodings.quopri_codec • encodings.raw_unicode_escape • encodings.rot_13 • encodings.shift_jis • encodings.shift_jis_2004 • encodings.shift_jisx0213 • encodings.tis_620 • encodings.undefined • encodings.unicode_escape • encodings.utf_16 • encodings.utf_16_be • encodings.utf_16_le • encodings.utf_32 • encodings.utf_32_be • encodings.utf_32_le • encodings.utf_7 • encodings.utf_8 • encodings.utf_8_sig • encodings.uu_codec • encodings.zlib_codec • interface_pagina_unica.py • locale

encodings.aliases SourceModule

imports: encodings

imported by: encodings • interface_pagina_unica.py • locale

encodings.ascii SourceModule

imports: codecs • encodings

imported by: encodings • interface_pagina_unica.py

encodings.base64_codec SourceModule

imports: base64 • codecs • encodings

imported by: encodings • interface_pagina_unica.py

encodings.big5 SourceModule

imports: _codecs_tw • _multibytecodec • codecs • encodings

imported by: encodings • interface_pagina_unica.py

encodings.big5hkscs SourceModule

imports: _codecs_hk • _multibytecodec • codecs • encodings

imported by: encodings • interface_pagina_unica.py

encodings.bz2_codec SourceModule

imports: bz2 • codecs • encodings

imported by: encodings • interface_pagina_unica.py

encodings.charmap SourceModule

imports: codecs • encodings

imported by: encodings • interface_pagina_unica.py

encodings.cp037 SourceModule

imports: codecs • encodings

imported by: encodings • interface_pagina_unica.py

encodings.cp1006 SourceModule

imports: codecs • encodings

imported by: encodings • interface_pagina_unica.py

encodings.cp1026 SourceModule

imports: codecs • encodings

imported by: encodings • interface_pagina_unica.py

encodings.cp1125 SourceModule

imports: codecs • encodings

imported by: encodings • interface_pagina_unica.py

encodings.cp1140 SourceModule

imports: codecs • encodings

imported by: encodings • interface_pagina_unica.py

encodings.cp1250 SourceModule

imports: codecs • encodings

imported by: encodings • interface_pagina_unica.py

encodings.cp1251 SourceModule

imports: codecs • encodings

imported by: encodings • interface_pagina_unica.py

encodings.cp1252 SourceModule

imports: codecs • encodings

imported by: encodings • interface_pagina_unica.py

encodings.cp1253 SourceModule

imports: codecs • encodings

imported by: encodings • interface_pagina_unica.py

encodings.cp1254 SourceModule

imports: codecs • encodings

imported by: encodings • interface_pagina_unica.py

encodings.cp1255 SourceModule

imports: codecs • encodings

imported by: encodings • interface_pagina_unica.py

encodings.cp1256 SourceModule

imports: codecs • encodings

imported by: encodings • interface_pagina_unica.py

encodings.cp1257 SourceModule

imports: codecs • encodings

imported by: encodings • interface_pagina_unica.py

encodings.cp1258 SourceModule

imports: codecs • encodings

imported by: encodings • interface_pagina_unica.py

encodings.cp273 SourceModule

imports: codecs • encodings

imported by: encodings • interface_pagina_unica.py

encodings.cp424 SourceModule

imports: codecs • encodings

imported by: encodings • interface_pagina_unica.py

encodings.cp437 SourceModule

imports: codecs • encodings

imported by: encodings • interface_pagina_unica.py

encodings.cp500 SourceModule

imports: codecs • encodings

imported by: encodings • interface_pagina_unica.py

encodings.cp720 SourceModule

imports: codecs • encodings

imported by: encodings • interface_pagina_unica.py

encodings.cp737 SourceModule

imports: codecs • encodings

imported by: encodings • interface_pagina_unica.py

encodings.cp775 SourceModule

imports: codecs • encodings

imported by: encodings • interface_pagina_unica.py

encodings.cp850 SourceModule

imports: codecs • encodings

imported by: encodings • interface_pagina_unica.py

encodings.cp852 SourceModule

imports: codecs • encodings

imported by: encodings • interface_pagina_unica.py

encodings.cp855 SourceModule

imports: codecs • encodings

imported by: encodings • interface_pagina_unica.py

encodings.cp856 SourceModule

imports: codecs • encodings

imported by: encodings • interface_pagina_unica.py

encodings.cp857 SourceModule

imports: codecs • encodings

imported by: encodings • interface_pagina_unica.py

encodings.cp858 SourceModule

imports: codecs • encodings

imported by: encodings • interface_pagina_unica.py

encodings.cp860 SourceModule

imports: codecs • encodings

imported by: encodings • interface_pagina_unica.py

encodings.cp861 SourceModule

imports: codecs • encodings

imported by: encodings • interface_pagina_unica.py

encodings.cp862 SourceModule

imports: codecs • encodings

imported by: encodings • interface_pagina_unica.py

encodings.cp863 SourceModule

imports: codecs • encodings

imported by: encodings • interface_pagina_unica.py

encodings.cp864 SourceModule

imports: codecs • encodings

imported by: encodings • interface_pagina_unica.py

encodings.cp865 SourceModule

imports: codecs • encodings

imported by: encodings • interface_pagina_unica.py

encodings.cp866 SourceModule

imports: codecs • encodings

imported by: encodings • interface_pagina_unica.py

encodings.cp869 SourceModule

imports: codecs • encodings

imported by: encodings • interface_pagina_unica.py

encodings.cp874 SourceModule

imports: codecs • encodings

imported by: encodings • interface_pagina_unica.py

encodings.cp875 SourceModule

imports: codecs • encodings

imported by: encodings • interface_pagina_unica.py

encodings.cp932 SourceModule

imports: _codecs_jp • _multibytecodec • codecs • encodings

imported by: encodings • interface_pagina_unica.py

encodings.cp949 SourceModule

imports: _codecs_kr • _multibytecodec • codecs • encodings

imported by: encodings • interface_pagina_unica.py

encodings.cp950 SourceModule

imports: _codecs_tw • _multibytecodec • codecs • encodings

imported by: encodings • interface_pagina_unica.py

encodings.euc_jis_2004 SourceModule

imports: _codecs_jp • _multibytecodec • codecs • encodings

imported by: encodings • interface_pagina_unica.py

encodings.euc_jisx0213 SourceModule

imports: _codecs_jp • _multibytecodec • codecs • encodings

imported by: encodings • interface_pagina_unica.py

encodings.euc_jp SourceModule

imports: _codecs_jp • _multibytecodec • codecs • encodings

imported by: encodings • interface_pagina_unica.py

encodings.euc_kr SourceModule

imports: _codecs_kr • _multibytecodec • codecs • encodings

imported by: encodings • interface_pagina_unica.py

encodings.gb18030 SourceModule

imports: _codecs_cn • _multibytecodec • codecs • encodings

imported by: encodings • interface_pagina_unica.py

encodings.gb2312 SourceModule

imports: _codecs_cn • _multibytecodec • codecs • encodings

imported by: encodings • interface_pagina_unica.py

encodings.gbk SourceModule

imports: _codecs_cn • _multibytecodec • codecs • encodings

imported by: encodings • interface_pagina_unica.py

encodings.hex_codec SourceModule

imports: binascii • codecs • encodings

imported by: encodings • interface_pagina_unica.py

encodings.hp_roman8 SourceModule

imports: codecs • encodings

imported by: encodings • interface_pagina_unica.py

encodings.hz SourceModule

imports: _codecs_cn • _multibytecodec • codecs • encodings

imported by: encodings • interface_pagina_unica.py

encodings.idna SourceModule

imports: codecs • encodings • re • stringprep • unicodedata

imported by: encodings • interface_pagina_unica.py

encodings.iso2022_jp SourceModule

imports: _codecs_iso2022 • _multibytecodec • codecs • encodings

imported by: encodings • interface_pagina_unica.py

encodings.iso2022_jp_1 SourceModule

imports: _codecs_iso2022 • _multibytecodec • codecs • encodings

imported by: encodings • interface_pagina_unica.py

encodings.iso2022_jp_2 SourceModule

imports: _codecs_iso2022 • _multibytecodec • codecs • encodings

imported by: encodings • interface_pagina_unica.py

encodings.iso2022_jp_2004 SourceModule

imports: _codecs_iso2022 • _multibytecodec • codecs • encodings

imported by: encodings • interface_pagina_unica.py

encodings.iso2022_jp_3 SourceModule

imports: _codecs_iso2022 • _multibytecodec • codecs • encodings

imported by: encodings • interface_pagina_unica.py

encodings.iso2022_jp_ext SourceModule

imports: _codecs_iso2022 • _multibytecodec • codecs • encodings

imported by: encodings • interface_pagina_unica.py

encodings.iso2022_kr SourceModule

imports: _codecs_iso2022 • _multibytecodec • codecs • encodings

imported by: encodings • interface_pagina_unica.py

encodings.iso8859_1 SourceModule

imports: codecs • encodings

imported by: encodings • interface_pagina_unica.py

encodings.iso8859_10 SourceModule

imports: codecs • encodings

imported by: encodings • interface_pagina_unica.py

encodings.iso8859_11 SourceModule

imports: codecs • encodings

imported by: encodings • interface_pagina_unica.py

encodings.iso8859_13 SourceModule

imports: codecs • encodings

imported by: encodings • interface_pagina_unica.py

encodings.iso8859_14 SourceModule

imports: codecs • encodings

imported by: encodings • interface_pagina_unica.py

encodings.iso8859_15 SourceModule

imports: codecs • encodings

imported by: encodings • interface_pagina_unica.py

encodings.iso8859_16 SourceModule

imports: codecs • encodings

imported by: encodings • interface_pagina_unica.py

encodings.iso8859_2 SourceModule

imports: codecs • encodings

imported by: encodings • interface_pagina_unica.py

encodings.iso8859_3 SourceModule

imports: codecs • encodings

imported by: encodings • interface_pagina_unica.py

encodings.iso8859_4 SourceModule

imports: codecs • encodings

imported by: encodings • interface_pagina_unica.py

encodings.iso8859_5 SourceModule

imports: codecs • encodings

imported by: encodings • interface_pagina_unica.py

encodings.iso8859_6 SourceModule

imports: codecs • encodings

imported by: encodings • interface_pagina_unica.py

encodings.iso8859_7 SourceModule

imports: codecs • encodings

imported by: encodings • interface_pagina_unica.py

encodings.iso8859_8 SourceModule

imports: codecs • encodings

imported by: encodings • interface_pagina_unica.py

encodings.iso8859_9 SourceModule

imports: codecs • encodings

imported by: encodings • interface_pagina_unica.py

encodings.johab SourceModule

imports: _codecs_kr • _multibytecodec • codecs • encodings

imported by: encodings • interface_pagina_unica.py

encodings.koi8_r SourceModule

imports: codecs • encodings

imported by: encodings • interface_pagina_unica.py

encodings.koi8_t SourceModule

imports: codecs • encodings

imported by: encodings • interface_pagina_unica.py

encodings.koi8_u SourceModule

imports: codecs • encodings

imported by: encodings • interface_pagina_unica.py

encodings.kz1048 SourceModule

imports: codecs • encodings

imported by: encodings • interface_pagina_unica.py

encodings.latin_1 SourceModule

imports: codecs • encodings

imported by: encodings • interface_pagina_unica.py

encodings.mac_arabic SourceModule

imports: codecs • encodings

imported by: encodings • interface_pagina_unica.py

encodings.mac_croatian SourceModule

imports: codecs • encodings

imported by: encodings • interface_pagina_unica.py

encodings.mac_cyrillic SourceModule

imports: codecs • encodings

imported by: encodings • interface_pagina_unica.py

encodings.mac_farsi SourceModule

imports: codecs • encodings

imported by: encodings • interface_pagina_unica.py

encodings.mac_greek SourceModule

imports: codecs • encodings

imported by: encodings • interface_pagina_unica.py

encodings.mac_iceland SourceModule

imports: codecs • encodings

imported by: encodings • interface_pagina_unica.py

encodings.mac_latin2 SourceModule

imports: codecs • encodings

imported by: encodings • interface_pagina_unica.py

encodings.mac_roman SourceModule

imports: codecs • encodings

imported by: encodings • interface_pagina_unica.py

encodings.mac_romanian SourceModule

imports: codecs • encodings

imported by: encodings • interface_pagina_unica.py

encodings.mac_turkish SourceModule

imports: codecs • encodings

imported by: encodings • interface_pagina_unica.py

encodings.mbcs SourceModule

imports: codecs • encodings

imported by: encodings • interface_pagina_unica.py

encodings.oem SourceModule

imports: codecs • encodings

imported by: encodings • interface_pagina_unica.py

encodings.palmos SourceModule

imports: codecs • encodings

imported by: encodings • interface_pagina_unica.py

encodings.ptcp154 SourceModule

imports: codecs • encodings

imported by: encodings • interface_pagina_unica.py

encodings.punycode SourceModule

imports: codecs • encodings

imported by: encodings • interface_pagina_unica.py

encodings.quopri_codec SourceModule

imports: codecs • encodings • io • quopri

imported by: encodings • interface_pagina_unica.py

encodings.raw_unicode_escape SourceModule

imports: codecs • encodings

imported by: encodings • interface_pagina_unica.py

encodings.rot_13 SourceModule

imports: codecs • encodings • sys

imported by: encodings • interface_pagina_unica.py

encodings.shift_jis SourceModule

imports: _codecs_jp • _multibytecodec • codecs • encodings

imported by: encodings • interface_pagina_unica.py

encodings.shift_jis_2004 SourceModule

imports: _codecs_jp • _multibytecodec • codecs • encodings

imported by: encodings • interface_pagina_unica.py

encodings.shift_jisx0213 SourceModule

imports: _codecs_jp • _multibytecodec • codecs • encodings

imported by: encodings • interface_pagina_unica.py

encodings.tis_620 SourceModule

imports: codecs • encodings

imported by: encodings • interface_pagina_unica.py

encodings.undefined SourceModule

imports: codecs • encodings

imported by: encodings • interface_pagina_unica.py

encodings.unicode_escape SourceModule

imports: codecs • encodings

imported by: encodings • interface_pagina_unica.py

encodings.utf_16 SourceModule

imports: codecs • encodings • sys

imported by: encodings • interface_pagina_unica.py

encodings.utf_16_be SourceModule

imports: codecs • encodings

imported by: encodings • interface_pagina_unica.py

encodings.utf_16_le SourceModule

imports: codecs • encodings

imported by: encodings • interface_pagina_unica.py

encodings.utf_32 SourceModule

imports: codecs • encodings • sys

imported by: encodings • interface_pagina_unica.py

encodings.utf_32_be SourceModule

imports: codecs • encodings

imported by: encodings • interface_pagina_unica.py

encodings.utf_32_le SourceModule

imports: codecs • encodings

imported by: encodings • interface_pagina_unica.py

encodings.utf_7 SourceModule

imports: codecs • encodings

imported by: encodings • interface_pagina_unica.py

encodings.utf_8 SourceModule

imports: codecs • encodings

imported by: encodings • interface_pagina_unica.py

encodings.utf_8_sig SourceModule

imports: codecs • encodings

imported by: encodings • interface_pagina_unica.py

encodings.uu_codec SourceModule

imports: binascii • codecs • encodings • io

imported by: encodings • interface_pagina_unica.py

encodings.zlib_codec SourceModule

imports: codecs • encodings • zlib

imported by: encodings • interface_pagina_unica.py

enum SourceModule

imports: sys • types

imported by: ast • asyncio.constants • http • inspect • interface_pagina_unica.py • plistlib • py_compile • re • signal • socket • ssl • tkinter

errno (builtin module)

imported by: asyncio.selector_events • asyncio.unix_events • asyncio.windows_events • distutils.dir_util • distutils.file_util • gettext • gzip • multiprocessing.forkserver • multiprocessing.queues • multiprocessing.shared_memory • pathlib • serial.serialposix • shutil • socket • ssl • subprocess • tempfile • test.support • xmlrpc.client

fcntl MissingModule

imported by: serial.serialposix

fnmatch SourceModule

imports: functools • itertools • os • posixpath • re

imported by: bdb • distutils.filelist • glob • pathlib • shutil • test.support • tkinter.filedialog • tracemalloc • unittest.loader • urllib.request

fractions SourceModule

imports: decimal • math • numbers • operator • re • sys

imported by: statistics

ftplib SourceModule

imports: netrc • re • socket • ssl • sys • warnings

imported by: urllib.request

functools SourceModule

imports: _functools • _thread • abc • collections • reprlib • types • typing • weakref

imported by: asyncio.base_events • asyncio.coroutines • asyncio.format_helpers • asyncio.selector_events • asyncio.tasks • asyncio.threads • concurrent.futures.process • configparser • contextlib • distutils.filelist • email._encoded_words • email.charset • fnmatch • http.server • importlib.metadata • importlib.util • inspect • interface_pagina_unica.py • linecache • locale • multiprocessing.reduction • multiprocessing.shared_memory • operator • pathlib • pickle • pkgutil • platform • re • signal • tempfile • test.support • test.support.testresult • threading • tracemalloc • types • typing • unittest.case • unittest.loader • unittest.result • unittest.signals

gc (builtin module)

imports: time

imported by: _posixsubprocess • test.support • weakref

genericpath SourceModule

imports: os • stat

imported by: ntpath • posixpath

getopt SourceModule

imports: gettext • os • sys

imported by: base64 • distutils.fancy_getopt • mimetypes • pdb • pydoc • quopri • webbrowser

getpass SourceModule

imports: contextlib • io • msvcrt • os • pwd • sys • termios • warnings

imported by: urllib.request

gettext SourceModule

imports: builtins • copy • errno • locale • os • re • struct • sys • warnings

imported by: argparse • getopt • optparse

glob SourceModule

imports: fnmatch • os • re • sys

imported by: pdb • serial.tools.list_ports_common • serial.tools.list_ports_linux • serial.tools.list_ports_posix • test.support • webbrowser

grp MissingModule

imported by: pathlib • shutil • subprocess • tarfile

gzip SourceModule

imports: _compression • argparse • builtins • errno • io • os • struct • sys • time • warnings • zlib

imported by: tarfile • test.support • xmlrpc.client

hashlib SourceModule

imports: _blake2 • _hashlib • _md5 • _sha1 • _sha256 • _sha3 • _sha512 • logging

imported by: hmac • random • urllib.request

heapq SourceModule

imports: _heapq

imported by: asyncio.base_events • asyncio.queues • collections • difflib • interface_pagina_unica.py • queue

hmac SourceModule

imports: _hashlib • _operator • hashlib • warnings

imported by: multiprocessing.connection • secrets

html Package

imports: html.entities • re

imported by: html.entities • http.server

html.entities SourceModule

imports: html

imported by: html

http Package

imports: enum

imported by: http.client • http.cookiejar • http.server

http.client SourceModule

imports: collections.abc • email.message • email.parser • http • io • re • socket • ssl • urllib.parse • warnings

imported by: http.cookiejar • http.server • urllib.request • xmlrpc.client

http.cookiejar SourceModule

imports: calendar • copy • datetime • http • http.client • io • logging • os • re • threading • time • traceback • urllib.parse • urllib.request • warnings

imported by: urllib.request

http.server SourceModule

imports: argparse • base64 • binascii • contextlib • copy • datetime • email.utils • functools • html • http • http.client • io • mimetypes • os • posixpath • pwd • select • shutil • socket • socketserver • subprocess • sys • time • urllib.parse

imported by: pydoc

importlib Package

imports: _frozen_importlib • _frozen_importlib_external • _imp • importlib • importlib._bootstrap • importlib._bootstrap_external • importlib.machinery • sys • types • warnings

imported by: importlib • importlib._bootstrap • importlib._bootstrap_external • importlib.abc • importlib.machinery • importlib.metadata • importlib.util • inspect • pkgutil • serial • test.support

importlib._bootstrap SourceModule

imports: _frozen_importlib_external • importlib

imported by: importlib • importlib.abc • importlib.machinery • importlib.util • pydoc

importlib._bootstrap_external SourceModule

imports: importlib • importlib.metadata • tokenize

imported by: importlib • importlib.abc • importlib.machinery • importlib.util • py_compile • pydoc

importlib.abc SourceModule

imports: _frozen_importlib • _frozen_importlib_external • abc • importlib • importlib._bootstrap • importlib._bootstrap_external • importlib.machinery • typing • warnings

imported by: importlib.metadata • importlib.util • zipimport

importlib.machinery SourceModule

imports: _imp • importlib • importlib._bootstrap • importlib._bootstrap_external

imported by: ctypes.util • importlib • importlib.abc • inspect • pkgutil • py_compile • pydoc • runpy

importlib.metadata SourceModule

imports: abc • collections • configparser • contextlib • csv • email • functools • importlib • importlib.abc • io • itertools • operator • os • pathlib • pep517 • posixpath • re • sys • zipfile

imported by: importlib._bootstrap_external

importlib.util SourceModule

imports: _imp • contextlib • functools • importlib • importlib._bootstrap • importlib._bootstrap_external • importlib.abc • sys • types • warnings

imported by: distutils.util • pkgutil • py_compile • pydoc • runpy • test.support • zipfile

inspect SourceModule

imports: abc • argparse • ast • builtins • collections • collections.abc • dis • enum • functools • importlib • importlib.machinery • itertools • linecache • operator • os • re • sys • token • tokenize • types • warnings

imported by: ast • asyncio.coroutines • asyncio.format_helpers • asyncio.tasks • bdb • doctest • pdb • pkgutil • pydoc • unittest.async_case

io SourceModule

imports: _io • abc

imported by: _compression • asyncio.proactor_events • asyncio.unix_events • bz2 • configparser • csv • dis • distutils.text_file • doctest • email.feedparser • email.generator • email.iterators • email.message • email.parser • encodings.quopri_codec • encodings.uu_codec • getpass • gzip • http.client • http.cookiejar • http.server • importlib.metadata • interface_pagina_unica.py • lib2to3.patcomp • lib2to3.pgen2.driver • lib2to3.pytree • lib2to3.refactor • logging • lzma • multiprocessing.connection • multiprocessing.popen_forkserver • multiprocessing.popen_spawn_posix • multiprocessing.reduction • os • pathlib • pdb • pickle • plistlib • pprint • pydoc • quopri • runpy • serial.serialutil • shlex • socket • socketserver • subprocess • tarfile • tempfile • test.support • test.support.testresult • tokenize • unittest.result • urllib.request • xml.etree.ElementTree • xml.sax • xml.sax.saxutils • xmlrpc.client • zipfile • zipimport

itertools (builtin module)

imported by: _pydecimal • asyncio.base_events • asyncio.tasks • asyncio.unix_events • asyncio.windows_utils • calendar • collections • concurrent.futures.process • concurrent.futures.thread • configparser • ctypes.macholib.dyld • fnmatch • importlib.metadata • inspect • lib2to3.btm_matcher • lib2to3.refactor • multiprocessing.connection • multiprocessing.pool • multiprocessing.process • multiprocessing.util • pickle • platform • plistlib • random • reprlib • statistics • threading • tokenize • traceback • weakref • zipfile

java MissingModule

imported by: platform

json Package

imports: codecs • json.decoder • json.encoder • json.scanner

imported by: interface_pagina_unica.py • json.decoder • json.encoder • json.scanner

json.decoder SourceModule

imports: _json • json • json.scanner • re

imported by: _json • json

json.encoder SourceModule

imports: _json • json • re

imported by: json

json.scanner SourceModule

imports: _json • json • re

imported by: json • json.decoder

keyword SourceModule

imported by: collections • interface_pagina_unica.py

linecache SourceModule

imports: functools • os • sys • tokenize

imported by: asyncio.base_tasks • bdb • doctest • inspect • interface_pagina_unica.py • pdb • traceback • tracemalloc • warnings

locale SourceModule

imports: _bootlocale • _collections_abc • _locale • builtins • encodings • encodings.aliases • functools • os • re • sys • warnings

imported by: _bootlocale • _pydecimal • _strptime • calendar • gettext • interface_pagina_unica.py • test.support • tkinter.filedialog • xml.etree.ElementTree

logging Package

imports: atexit • collections.abc • io • os • pickle • re • string • sys • threading • time • traceback • warnings • weakref

imported by: asyncio.futures • asyncio.log • concurrent.futures._base • hashlib • http.cookiejar • lib2to3.btm_matcher • lib2to3.pgen2.driver • lib2to3.refactor • multiprocessing.util • unittest._log

lzma SourceModule

imports: _compression • _lzma • builtins • io • os

imported by: shutil • tarfile • test.support • zipfile

marshal (builtin module)

imported by: pkgutil • zipimport

math (builtin module)

imported by: _pydecimal • asyncio.windows_events • datetime • fractions • random • selectors • statistics

mimetypes SourceModule

imports: getopt • os • posixpath • sys • urllib.parse • winreg

imported by: http.server • urllib.request

mmap (builtin module)

imported by: multiprocessing.heap • multiprocessing.shared_memory

msvcrt (builtin module)

imported by: asyncio.windows_events • asyncio.windows_utils • getpass • multiprocessing.popen_spawn_win32 • multiprocessing.spawn • subprocess • test.support

multiprocessing Package

imports: multiprocessing • multiprocessing.AuthenticationError • multiprocessing.BufferTooShort • multiprocessing.TimeoutError • multiprocessing.connection • multiprocessing.context • multiprocessing.forkserver • multiprocessing.get_context • multiprocessing.get_start_method • multiprocessing.pool • multiprocessing.process • multiprocessing.reduction • multiprocessing.resource_sharer • multiprocessing.resource_tracker • multiprocessing.set_start_method • multiprocessing.shared_memory • multiprocessing.spawn • multiprocessing.util • sys

imported by: concurrent.futures.process • lib2to3.refactor • multiprocessing • multiprocessing.connection • multiprocessing.context • multiprocessing.dummy • multiprocessing.forkserver • multiprocessing.heap • multiprocessing.managers • multiprocessing.pool • multiprocessing.popen_fork • multiprocessing.popen_forkserver • multiprocessing.popen_spawn_posix • multiprocessing.popen_spawn_win32 • multiprocessing.process • multiprocessing.queues • multiprocessing.reduction • multiprocessing.resource_sharer • multiprocessing.resource_tracker • multiprocessing.shared_memory • multiprocessing.sharedctypes • multiprocessing.spawn • multiprocessing.synchronize • multiprocessing.util • pyi_rth_multiprocessing.py

multiprocessing.AuthenticationError MissingModule

imported by: multiprocessing • multiprocessing.connection

multiprocessing.BufferTooShort MissingModule

imported by: multiprocessing • multiprocessing.connection

multiprocessing.TimeoutError MissingModule

imported by: multiprocessing • multiprocessing.pool

multiprocessing.connection SourceModule

imports: _multiprocessing • _winapi • hmac • io • itertools • multiprocessing • multiprocessing.AuthenticationError • multiprocessing.BufferTooShort • multiprocessing.context • multiprocessing.resource_sharer • multiprocessing.util • os • selectors • socket • struct • sys • tempfile • time • xmlrpc.client

imported by: concurrent.futures.process • multiprocessing • multiprocessing.context • multiprocessing.forkserver • multiprocessing.managers • multiprocessing.pool • multiprocessing.popen_fork • multiprocessing.popen_forkserver • multiprocessing.process • multiprocessing.queues • multiprocessing.resource_sharer

multiprocessing.context SourceModule

imports: multiprocessing • multiprocessing.connection • multiprocessing.forkserver • multiprocessing.managers • multiprocessing.pool • multiprocessing.popen_fork • multiprocessing.popen_forkserver • multiprocessing.popen_spawn_posix • multiprocessing.popen_spawn_win32 • multiprocessing.process • multiprocessing.queues • multiprocessing.reduction • multiprocessing.sharedctypes • multiprocessing.spawn • multiprocessing.synchronize • multiprocessing.util • os • sys • threading

imported by: multiprocessing • multiprocessing.connection • multiprocessing.forkserver • multiprocessing.heap • multiprocessing.managers • multiprocessing.popen_forkserver • multiprocessing.popen_spawn_posix • multiprocessing.popen_spawn_win32 • multiprocessing.process • multiprocessing.queues • multiprocessing.reduction • multiprocessing.resource_sharer • multiprocessing.sharedctypes • multiprocessing.spawn • multiprocessing.synchronize

multiprocessing.dummy Package

imports: array • multiprocessing • multiprocessing.dummy.connection • multiprocessing.pool • queue • sys • threading • weakref

imported by: multiprocessing.dummy.connection • multiprocessing.pool

multiprocessing.dummy.connection SourceModule

imports: multiprocessing.dummy • queue

imported by: multiprocessing.dummy

multiprocessing.forkserver SourceModule

imports: errno • multiprocessing • multiprocessing.connection • multiprocessing.context • multiprocessing.process • multiprocessing.resource_tracker • multiprocessing.spawn • multiprocessing.util • os • selectors • signal • socket • struct • sys • threading • warnings

imported by: multiprocessing • multiprocessing.context • multiprocessing.popen_forkserver • multiprocessing.util

multiprocessing.get_context MissingModule

imported by: multiprocessing • multiprocessing.managers • multiprocessing.pool • multiprocessing.sharedctypes

multiprocessing.get_start_method MissingModule

imported by: multiprocessing • multiprocessing.spawn

multiprocessing.heap SourceModule

imports: _winapi • bisect • collections • mmap • multiprocessing • multiprocessing.context • multiprocessing.util • os • sys • tempfile • threading

imported by: multiprocessing.sharedctypes • multiprocessing.synchronize

multiprocessing.managers SourceModule

imports: array • multiprocessing • multiprocessing.connection • multiprocessing.context • multiprocessing.get_context • multiprocessing.pool • multiprocessing.process • multiprocessing.resource_tracker • multiprocessing.shared_memory • multiprocessing.util • os • queue • signal • sys • threading • time • traceback • types

imported by: multiprocessing.context

multiprocessing.pool SourceModule

imports: collections • itertools • multiprocessing • multiprocessing.TimeoutError • multiprocessing.connection • multiprocessing.dummy • multiprocessing.get_context • multiprocessing.util • os • queue • threading • time • traceback • types • warnings

imported by: multiprocessing • multiprocessing.context • multiprocessing.dummy • multiprocessing.managers

multiprocessing.popen_fork SourceModule

imports: multiprocessing • multiprocessing.connection • multiprocessing.util • os • signal

imported by: multiprocessing.context • multiprocessing.popen_forkserver • multiprocessing.popen_spawn_posix • pyi_rth_multiprocessing.py

multiprocessing.popen_forkserver SourceModule

imports: io • multiprocessing • multiprocessing.connection • multiprocessing.context • multiprocessing.forkserver • multiprocessing.popen_fork • multiprocessing.spawn • multiprocessing.util • os

imported by: multiprocessing.context

multiprocessing.popen_spawn_posix SourceModule

imports: io • multiprocessing • multiprocessing.context • multiprocessing.popen_fork • multiprocessing.resource_tracker • multiprocessing.spawn • multiprocessing.util • os

imported by: multiprocessing.context • pyi_rth_multiprocessing.py

multiprocessing.popen_spawn_win32 SourceModule

imports: _winapi • msvcrt • multiprocessing • multiprocessing.context • multiprocessing.spawn • multiprocessing.util • os • signal • sys

imported by: multiprocessing.context • pyi_rth_multiprocessing.py

multiprocessing.process SourceModule

imports: _weakrefset • itertools • multiprocessing • multiprocessing.connection • multiprocessing.context • multiprocessing.util • os • signal • sys • threading • traceback

imported by: multiprocessing • multiprocessing.context • multiprocessing.forkserver • multiprocessing.managers • multiprocessing.resource_sharer • multiprocessing.spawn • multiprocessing.synchronize • multiprocessing.util

multiprocessing.queues SourceModule

imports: _multiprocessing • collections • errno • multiprocessing • multiprocessing.connection • multiprocessing.context • multiprocessing.synchronize • multiprocessing.util • os • queue • sys • threading • time • traceback • types • weakref

imported by: concurrent.futures.process • multiprocessing.context

multiprocessing.reduction SourceModule

imports: _winapi • abc • array • copyreg • functools • io • multiprocessing • multiprocessing.context • multiprocessing.resource_sharer • os • pickle • socket • sys

imported by: multiprocessing • multiprocessing.context

multiprocessing.resource_sharer SourceModule

imports: multiprocessing • multiprocessing.connection • multiprocessing.context • multiprocessing.process • multiprocessing.util • os • signal • socket • sys • threading

imported by: multiprocessing • multiprocessing.connection • multiprocessing.reduction

multiprocessing.resource_tracker SourceModule

imports: _multiprocessing • _posixshmem • multiprocessing • multiprocessing.spawn • multiprocessing.util • os • signal • sys • threading • warnings

imported by: multiprocessing • multiprocessing.forkserver • multiprocessing.managers • multiprocessing.popen_spawn_posix • multiprocessing.shared_memory • multiprocessing.spawn • multiprocessing.synchronize • multiprocessing.util

multiprocessing.set_start_method MissingModule

imported by: multiprocessing • multiprocessing.spawn

multiprocessing.shared_memory SourceModule

imports: _posixshmem • _winapi • errno • functools • mmap • multiprocessing • multiprocessing.resource_tracker • os • secrets • struct • types

imported by: multiprocessing • multiprocessing.managers

multiprocessing.sharedctypes SourceModule

imports: ctypes • multiprocessing • multiprocessing.context • multiprocessing.get_context • multiprocessing.heap • weakref

imported by: multiprocessing.context

multiprocessing.spawn SourceModule

imports: _winapi • msvcrt • multiprocessing • multiprocessing.context • multiprocessing.get_start_method • multiprocessing.process • multiprocessing.resource_tracker • multiprocessing.set_start_method • multiprocessing.util • os • runpy • sys • types

imported by: multiprocessing • multiprocessing.context • multiprocessing.forkserver • multiprocessing.popen_forkserver • multiprocessing.popen_spawn_posix • multiprocessing.popen_spawn_win32 • multiprocessing.resource_tracker • pyi_rth_multiprocessing.py

multiprocessing.synchronize SourceModule

imports: _multiprocessing • multiprocessing • multiprocessing.context • multiprocessing.heap • multiprocessing.process • multiprocessing.resource_tracker • multiprocessing.util • struct • sys • tempfile • threading • time

imported by: multiprocessing.context • multiprocessing.queues

multiprocessing.util SourceModule

imports: _posixsubprocess • atexit • itertools • logging • multiprocessing • multiprocessing.forkserver • multiprocessing.process • multiprocessing.resource_tracker • os • shutil • subprocess • sys • tempfile • threading • traceback • weakref

imported by: multiprocessing • multiprocessing.connection • multiprocessing.context • multiprocessing.forkserver • multiprocessing.heap • multiprocessing.managers • multiprocessing.pool • multiprocessing.popen_fork • multiprocessing.popen_forkserver • multiprocessing.popen_spawn_posix • multiprocessing.popen_spawn_win32 • multiprocessing.process • multiprocessing.queues • multiprocessing.resource_sharer • multiprocessing.resource_tracker • multiprocessing.spawn • multiprocessing.synchronize

netrc SourceModule

imports: os • pwd • shlex • stat

imported by: ftplib

nt (builtin module)

imported by: ctypes • ntpath • os • pathlib • shutil

ntpath SourceModule

imports: genericpath • nt • os • stat • string • sys

imported by: ntpath • os • pathlib

ntpath AliasNode

imports: ntpath • os

imported by: distutils.file_util • os • pkgutil • py_compile • serial.tools.list_ports_common • sysconfig • tracemalloc • unittest • unittest.util

nturl2path SourceModule

imports: string • urllib.parse

imported by: urllib.request

numbers SourceModule

imports: abc

imported by: _pydecimal • fractions • statistics

opcode SourceModule

imports: _opcode

imported by: dis

operator SourceModule

imports: _operator • builtins • functools

imported by: collections • email._header_value_parser • fractions • importlib.metadata • inspect • interface_pagina_unica.py • lib2to3.refactor • pathlib • statistics • typing

optparse SourceModule

imports: gettext • os • sys • textwrap

imported by: uu

org MissingModule

imported by: pickle

os SourceModule

imports: _collections_abc • abc • io • nt • ntpath • ntpath • posix • posixpath • stat • subprocess • sys • warnings

imported by: _bootsubprocess • _osx_support • argparse • asyncio.base_events • asyncio.coroutines • asyncio.events • asyncio.proactor_events • asyncio.unix_events • asyncio.windows_utils • bdb • bz2 • concurrent.futures.process • concurrent.futures.thread • configparser • ctypes • ctypes._aix • ctypes.macholib.dyld • ctypes.util • distutils.ccompiler • distutils.debug • distutils.dep_util • distutils.dir_util • distutils.file_util • distutils.filelist • distutils.spawn • distutils.sysconfig • distutils.util • doctest • email.utils • fnmatch • genericpath • getopt • getpass • gettext • glob • gzip • http.cookiejar • http.server • importlib.metadata • inspect • interface_pagina_unica.py • lib2to3.pgen2.driver • lib2to3.pygram • lib2to3.refactor • linecache • locale • logging • lzma • mimetypes • multiprocessing.connection • multiprocessing.context • multiprocessing.forkserver • multiprocessing.heap • multiprocessing.managers • multiprocessing.pool • multiprocessing.popen_fork • multiprocessing.popen_forkserver • multiprocessing.popen_spawn_posix • multiprocessing.popen_spawn_win32 • multiprocessing.process • multiprocessing.queues • multiprocessing.reduction • multiprocessing.resource_sharer • multiprocessing.resource_tracker • multiprocessing.shared_memory • multiprocessing.spawn • multiprocessing.util • netrc • ntpath • ntpath • optparse • pathlib • pdb • pkgutil • platform • plistlib • posixpath • py_compile • pydoc • pyi_rth__tkinter.py • pyi_rth_multiprocessing.py • random • runpy • serial • serial.serialposix • serial.tools.list_ports • serial.tools.list_ports_common • serial.tools.list_ports_linux • serial.tools.list_ports_posix • shlex • shutil • socket • socketserver • ssl • subprocess • sysconfig • tarfile • tempfile • test.support • threading • tkinter • tkinter.filedialog • unittest.loader • unittest.main • urllib.request • uu • webbrowser • xml.sax • xml.sax.saxutils • zipfile • zipimport

pathlib SourceModule

imports: _collections_abc • errno • fnmatch • functools • grp • io • nt • ntpath • operator • os • posixpath • pwd • re • stat • sys • urllib.parse

imported by: importlib.metadata • zipimport

pdb SourceModule

imports: bdb • cmd • code • dis • getopt • glob • inspect • io • linecache • os • pdb • pprint • pydoc • re • readline • runpy • shlex • signal • sys • tokenize • traceback

imported by: doctest • pdb

pep517 MissingModule

imported by: importlib.metadata

pickle SourceModule

imports: _compat_pickle • _pickle • codecs • copyreg • doctest • functools • io • itertools • org • pprint • re • struct • sys • types

imported by: lib2to3.pgen2.grammar • logging • multiprocessing.reduction • tracemalloc

pkgutil SourceModule

imports: collections • functools • importlib • importlib.machinery • importlib.util • inspect • marshal • ntpath • os • re • sys • types • warnings • zipimport

imported by: lib2to3.pgen2.driver • lib2to3.refactor • pydoc • runpy

platform SourceModule

imports: 'java.lang' • _winreg • collections • functools • itertools • java • os • plistlib • re • socket • struct • subprocess • sys • vms_lib • winreg

imported by: pydoc • test.support

plistlib SourceModule

imports: binascii • codecs • datetime • enum • io • itertools • os • re • struct • xml.parsers.expat

imported by: platform

posix MissingModule

imports: resource

imported by: os • shutil

posixpath SourceModule

imports: genericpath • os • pwd • re • stat • sys

imported by: fnmatch • http.server • importlib.metadata • mimetypes • os • pathlib • urllib.request • zipfile

pprint SourceModule

imports: collections • io • re • sys • time • types

imported by: lib2to3.pgen2.grammar • pdb • pickle • sysconfig • unittest.case

pwd MissingModule

imported by: distutils.util • getpass • http.server • netrc • pathlib • posixpath • shutil • subprocess • tarfile • webbrowser

py_compile SourceModule

imports: enum • importlib._bootstrap_external • importlib.machinery • importlib.util • ntpath • os • sys • traceback

imported by: distutils.util • zipfile

pydoc SourceModule

imports: builtins • collections • email.message • getopt • http.server • importlib._bootstrap • importlib._bootstrap_external • importlib.machinery • importlib.util • inspect • io • os • pkgutil • platform • pydoc_data.topics • re • reprlib • select • subprocess • sys • sysconfig • tempfile • textwrap • threading • time • tokenize • traceback • tty • urllib.parse • warnings • webbrowser

imported by: pdb

pydoc_data Package

imported by: pydoc_data.topics

pydoc_data.topics SourceModule

imports: pydoc_data

imported by: pydoc

pyexpat c:\program files\python39\DLLs\pyexpat.pyd

imported by: _elementtree • xml.etree.ElementTree • xml.parsers.expat

queue SourceModule

imports: _queue • collections • heapq • threading • time • types

imported by: concurrent.futures.process • concurrent.futures.thread • multiprocessing.dummy • multiprocessing.dummy.connection • multiprocessing.managers • multiprocessing.pool • multiprocessing.queues

quopri SourceModule

imports: binascii • getopt • io • sys

imported by: email.encoders • email.message • encodings.quopri_codec

random SourceModule

imports: _collections_abc • _random • _sha512 • bisect • hashlib • itertools • math • os • statistics • time • warnings

imported by: email.generator • email.utils • secrets • statistics • tempfile

re SourceModule

imports: _locale • copyreg • enum • functools • sre_compile • sre_constants • sre_parse

imported by: _osx_support • _pydecimal • _sre • _strptime • argparse • base64 • configparser • csv • ctypes._aix • ctypes.macholib.dylib • ctypes.macholib.framework • ctypes.util • difflib • distutils.ccompiler • distutils.fancy_getopt • distutils.filelist • distutils.sysconfig • distutils.util • doctest • email._encoded_words • email._header_value_parser • email.feedparser • email.generator • email.header • email.message • email.policy • email.quoprimime • email.utils • encodings.idna • fnmatch • fractions • ftplib • gettext • glob • html • http.client • http.cookiejar • importlib.metadata • inspect • interface_pagina_unica.py • json.decoder • json.encoder • json.scanner • lib2to3.pgen2.literals • lib2to3.pgen2.tokenize • locale • logging • pathlib • pdb • pickle • pkgutil • platform • plistlib • posixpath • pprint • pydoc • pyi_rth_multiprocessing.py • serial.tools.list_ports • serial.tools.list_ports_common • serial.tools.list_ports_windows • shlex • string • sysconfig • tarfile • test.support • textwrap • tkinter • tokenize • typing • unittest.case • unittest.loader • urllib.parse • urllib.request • warnings • xml.etree.ElementPath • xml.etree.ElementTree

readline MissingModule

imported by: cmd • code • pdb

reprlib SourceModule

imports: _thread • builtins • itertools

imported by: asyncio.base_futures • asyncio.format_helpers • bdb • collections • functools • interface_pagina_unica.py • pydoc

resource MissingModule

imported by: posix • test.support

runpy SourceModule

imports: importlib.machinery • importlib.util • io • os • pkgutil • sys • types • warnings

imported by: multiprocessing.spawn • pdb

secrets SourceModule

imports: base64 • binascii • hmac • random

imported by: multiprocessing.shared_memory

select c:\program files\python39\DLLs\select.pyd

imported by: http.server • pydoc • selectors • serial.serialposix • subprocess

selectors SourceModule

imports: abc • collections • collections.abc • math • select • sys

imported by: asyncio.selector_events • asyncio.unix_events • multiprocessing.connection • multiprocessing.forkserver • socket • socketserver • subprocess

serial Package

imports: __future__ • importlib • os • serial.serialcli • serial.serialjava • serial.serialposix • serial.serialutil • serial.serialwin32 • serial.win32 • sys

imported by: interface_pagina_unica.py • serial.serialcli • serial.serialjava • serial.serialposix • serial.serialutil • serial.serialwin32 • serial.tools • serial.tools.list_ports_posix • serial.tools.list_ports_windows • serial.win32

serial.serialcli SourceModule

imports: 'System.IO' • System • __future__ • serial • serial.serialutil

imported by: serial

serial.serialjava SourceModule

imports: __future__ • serial • serial.serialutil

imported by: serial

serial.serialposix SourceModule

imports: __future__ • array • errno • fcntl • os • select • serial • serial.serialutil • struct • sys • termios • warnings

imported by: serial

serial.serialutil SourceModule

imports: __future__ • array • io • serial • sys • time

imported by: serial • serial.serialcli • serial.serialjava • serial.serialposix • serial.serialwin32

serial.serialwin32 SourceModule

imports: __future__ • ctypes • serial • serial.serialutil • serial.win32 • time

imported by: serial

serial.tools Package

imports: serial • serial.tools.list_ports_common

imported by: serial.tools.list_ports • serial.tools.list_ports_common • serial.tools.list_ports_linux • serial.tools.list_ports_osx • serial.tools.list_ports_posix • serial.tools.list_ports_windows

serial.tools.list_ports SourceModule

imports: __future__ • argparse • os • re • serial.tools • serial.tools.list_ports_posix • serial.tools.list_ports_windows • sys

imported by: interface_pagina_unica.py

serial.tools.list_ports_common SourceModule

imports: __future__ • glob • ntpath • os • re • serial.tools

imported by: serial.tools • serial.tools.list_ports_linux • serial.tools.list_ports_osx • serial.tools.list_ports_posix • serial.tools.list_ports_windows

serial.tools.list_ports_linux SourceModule

imports: __future__ • glob • os • serial.tools • serial.tools.list_ports_common

imported by: serial.tools.list_ports_posix

serial.tools.list_ports_osx SourceModule

imports: __future__ • ctypes • serial.tools • serial.tools.list_ports_common

imported by: serial.tools.list_ports_posix

serial.tools.list_ports_posix SourceModule

imports: __future__ • glob • os • serial • serial.tools • serial.tools.list_ports_common • serial.tools.list_ports_linux • serial.tools.list_ports_osx • sys

imported by: serial.tools.list_ports

serial.tools.list_ports_windows SourceModule

imports: __future__ • ctypes • ctypes.wintypes • re • serial • serial.tools • serial.tools.list_ports_common • serial.win32

imported by: serial.tools.list_ports

serial.win32 SourceModule

imports: __future__ • ctypes • ctypes.wintypes • serial

imported by: serial • serial.serialwin32 • serial.tools.list_ports_windows

shlex SourceModule

imports: collections • io • os • re • sys • warnings

imported by: netrc • pdb • webbrowser

shutil SourceModule

imports: bz2 • collections • errno • fnmatch • grp • lzma • nt • os • posix • pwd • stat • sys • tarfile • zipfile • zlib

imported by: argparse • ctypes.util • http.server • multiprocessing.util • tarfile • tempfile • test.support • webbrowser • zipfile

signal SourceModule

imports: _signal • enum • functools

imported by: asyncio.proactor_events • asyncio.unix_events • multiprocessing.forkserver • multiprocessing.managers • multiprocessing.popen_fork • multiprocessing.popen_spawn_win32 • multiprocessing.process • multiprocessing.resource_sharer • multiprocessing.resource_tracker • pdb • subprocess • test.support • unittest.signals

socket SourceModule

imports: _socket • array • enum • errno • io • os • selectors • sys

imported by: _ssl • asyncio.base_events • asyncio.events • asyncio.proactor_events • asyncio.selector_events • asyncio.streams • asyncio.trsock • asyncio.unix_events • asyncio.windows_events • email.utils • ftplib • http.client • http.server • multiprocessing.connection • multiprocessing.forkserver • multiprocessing.reduction • multiprocessing.resource_sharer • platform • socketserver • ssl • urllib.request • webbrowser

socketserver SourceModule

imports: io • os • selectors • socket • sys • threading • time • traceback

imported by: http.server

sre_compile SourceModule

imports: _sre • sre_constants • sre_parse • sys

imported by: interface_pagina_unica.py • re

sre_constants SourceModule

imports: _sre

imported by: interface_pagina_unica.py • re • sre_compile • sre_parse

sre_parse SourceModule

imports: sre_constants • unicodedata • warnings

imported by: interface_pagina_unica.py • re • sre_compile

ssl SourceModule

imports: _ssl • base64 • calendar • collections • enum • errno • os • socket • sys • time • warnings

imported by: asyncio.base_events • asyncio.selector_events • asyncio.sslproto • ftplib • http.client • urllib.request

stat SourceModule

imports: _stat

imported by: asyncio.base_events • asyncio.unix_events • distutils.dep_util • distutils.file_util • genericpath • netrc • ntpath • os • pathlib • posixpath • shutil • tarfile • test.support • zipfile

statistics SourceModule

imports: _statistics • bisect • collections • decimal • fractions • itertools • math • numbers • operator • random

imported by: random

string SourceModule

imports: _string • collections • re

imported by: cmd • distutils.fancy_getopt • distutils.util • email._encoded_words • email._header_value_parser • email.quoprimime • lib2to3.pgen2.tokenize • logging • ntpath • nturl2path • urllib.request

stringprep SourceModule

imports: unicodedata

imported by: encodings.idna

struct SourceModule

imports: _struct

imported by: asyncio.windows_events • base64 • ctypes • ctypes.util • gettext • gzip • multiprocessing.connection • multiprocessing.forkserver • multiprocessing.shared_memory • multiprocessing.synchronize • pickle • platform • plistlib • serial.serialposix • tarfile • test.support • zipfile

subprocess SourceModule

imports: _posixsubprocess • _winapi • builtins • contextlib • errno • grp • io • msvcrt • os • pwd • select • selectors • signal • sys • threading • time • types • warnings

imported by: _aix_support • asyncio.base_events • asyncio.base_subprocess • asyncio.events • asyncio.subprocess • asyncio.unix_events • asyncio.windows_utils • ctypes._aix • ctypes.util • distutils.spawn • distutils.util • http.server • multiprocessing.util • os • platform • pydoc • pyi_rth_multiprocessing.py • test.support • webbrowser

sys (builtin module)

imported by: _aix_support • _bootlocale • _collections_abc • _osx_support • _pydecimal • argparse • ast • asyncio • asyncio.base_events • asyncio.coroutines • asyncio.events • asyncio.format_helpers • asyncio.futures • asyncio.streams • asyncio.unix_events • asyncio.windows_utils • base64 • bdb • calendar • cmd • code • codecs • collections • concurrent.futures.process • configparser • contextlib • ctypes • ctypes._aix • ctypes._endian • ctypes.util • datetime • dis • distutils • distutils.ccompiler • distutils.fancy_getopt • distutils.log • distutils.spawn • distutils.sysconfig • distutils.text_file • distutils.util • doctest • email._header_value_parser • email.generator • email.iterators • email.policy • encodings • encodings.rot_13 • encodings.utf_16 • encodings.utf_32 • enum • fractions • ftplib • getopt • getpass • gettext • glob • gzip • http.server • importlib • importlib.metadata • importlib.util • inspect • interface_pagina_unica.py • lib2to3.pgen2.driver • lib2to3.pgen2.tokenize • lib2to3.pytree • lib2to3.refactor • linecache • locale • logging • mimetypes • multiprocessing • multiprocessing.connection • multiprocessing.context • multiprocessing.dummy • multiprocessing.forkserver • multiprocessing.heap • multiprocessing.managers • multiprocessing.popen_spawn_win32 • multiprocessing.process • multiprocessing.queues • multiprocessing.reduction • multiprocessing.resource_sharer • multiprocessing.resource_tracker • multiprocessing.spawn • multiprocessing.synchronize • multiprocessing.util • ntpath • optparse • os • pathlib • pdb • pickle • pkgutil • platform • posixpath • pprint • py_compile • pydoc • pyi_rth__tkinter.py • pyi_rth_multiprocessing.py • quopri • runpy • selectors • serial • serial.serialposix • serial.serialutil • serial.tools.list_ports • serial.tools.list_ports_posix • shlex • shutil • socket • socketserver • sre_compile • ssl • subprocess • sysconfig • tarfile • tempfile • test.support • test.support.testresult • threading • tkinter • tkinter.filedialog • tokenize • traceback • types • typing • unittest.case • unittest.loader • unittest.main • unittest.result • unittest.runner • unittest.suite • urllib.parse • urllib.request • uu • warnings • weakref • webbrowser • xml.etree.ElementTree • xml.parsers.expat • xml.sax • xml.sax._exceptions • xml.sax.expatreader • xml.sax.saxutils • xmlrpc.client • zipfile • zipimport

sysconfig SourceModule

imports: _aix_support • _osx_support • ntpath • os • pprint • re • sys • types • warnings

imported by: _aix_support • pydoc • test.support

tarfile SourceModule

imports: argparse • builtins • bz2 • copy • grp • gzip • io • lzma • os • pwd • re • shutil • stat • struct • sys • time • zlib

imported by: shutil

tempfile SourceModule

imports: _thread • errno • functools • io • os • random • shutil • sys • types • warnings • weakref

imported by: _osx_support • asyncio.windows_utils • ctypes.util • distutils.ccompiler • distutils.util • multiprocessing.connection • multiprocessing.heap • multiprocessing.synchronize • multiprocessing.util • pydoc • test.support • urllib.request • urllib.response • webbrowser

termios MissingModule

imported by: getpass • serial.serialposix • tty

textwrap SourceModule

imports: re

imported by: argparse • optparse • pydoc

threading SourceModule

imports: _collections • _thread • _threading_local • _weakrefset • collections • functools • itertools • os • sys • time • traceback

imported by: _threading_local • asyncio.base_events • asyncio.events • asyncio.proactor_events • asyncio.unix_events • bz2 • concurrent.futures._base • concurrent.futures.process • concurrent.futures.thread • http.cookiejar • logging • multiprocessing.context • multiprocessing.dummy • multiprocessing.forkserver • multiprocessing.heap • multiprocessing.managers • multiprocessing.pool • multiprocessing.process • multiprocessing.queues • multiprocessing.resource_sharer • multiprocessing.resource_tracker • multiprocessing.synchronize • multiprocessing.util • pydoc • queue • socketserver • subprocess • test.support • webbrowser • zipfile

time (builtin module)

imports: _strptime

imported by: _datetime • _strptime • asyncio.base_events • asyncio.windows_events • concurrent.futures._base • datetime • email._parseaddr • email.generator • email.utils • gc • gzip • http.cookiejar • http.server • logging • multiprocessing.connection • multiprocessing.managers • multiprocessing.pool • multiprocessing.queues • multiprocessing.synchronize • pprint • pydoc • queue • random • serial.serialutil • serial.serialwin32 • socketserver • ssl • subprocess • tarfile • test.support • test.support.testresult • threading • unittest.runner • urllib.request • xmlrpc.client • zipfile • zipimport

tkinter Package

imports: _tkinter • enum • os • re • sys • tkinter.commondialog • tkinter.constants • tkinter.messagebox • traceback • types

imported by: interface_pagina_unica.py • test.support • tkinter.commondialog • tkinter.constants • tkinter.dialog • tkinter.filedialog • tkinter.messagebox

tkinter.commondialog SourceModule

imports: tkinter

imported by: tkinter • tkinter.filedialog • tkinter.messagebox

tkinter.constants SourceModule

imports: tkinter

imported by: tkinter

tkinter.dialog SourceModule

imports: tkinter

imported by: tkinter.filedialog

tkinter.filedialog SourceModule

imports: fnmatch • locale • os • sys • tkinter • tkinter.commondialog • tkinter.dialog

imported by: interface_pagina_unica.py

tkinter.messagebox SourceModule

imports: tkinter • tkinter.commondialog

imported by: interface_pagina_unica.py • tkinter

token SourceModule

imported by: inspect • tokenize

tokenize SourceModule

imports: argparse • builtins • codecs • collections • io • itertools • re • sys • token

imported by: importlib._bootstrap_external • inspect • linecache • pdb • pydoc

traceback SourceModule

imports: collections • itertools • linecache • sys

imported by: asyncio.base_events • asyncio.base_tasks • asyncio.coroutines • asyncio.format_helpers • code • concurrent.futures.process • doctest • http.cookiejar • interface_pagina_unica.py • logging • multiprocessing.managers • multiprocessing.pool • multiprocessing.process • multiprocessing.queues • multiprocessing.util • pdb • py_compile • pydoc • socketserver • test.support.testresult • threading • tkinter • unittest.case • unittest.loader • unittest.result • warnings

tracemalloc SourceModule

imports: _tracemalloc • collections.abc • fnmatch • functools • linecache • ntpath • pickle

imported by: test.support • warnings

tty SourceModule

imports: termios

imported by: pydoc

types SourceModule

imports: _collections_abc • functools • sys

imported by: _weakrefset • asyncio.coroutines • asyncio.tasks • concurrent.futures._base • concurrent.futures.thread • contextlib • copy • ctypes • difflib • dis • email.headerregistry • enum • functools • importlib • importlib.util • inspect • interface_pagina_unica.py • multiprocessing.managers • multiprocessing.pool • multiprocessing.queues • multiprocessing.shared_memory • multiprocessing.spawn • pickle • pkgutil • pprint • queue • runpy • subprocess • sysconfig • tempfile • test.support • tkinter • typing • unittest.case • unittest.loader • urllib.parse

typing SourceModule

imports: abc • collections • collections.abc • contextlib • functools • operator • re • sys • types

imported by: asyncio.staggered • functools • importlib.abc

unicodedata c:\program files\python39\DLLs\unicodedata.pyd

imported by: encodings.idna • sre_parse • stringprep • test.support • urllib.parse

unittest Package

imports: ntpath • unittest • unittest.async_case • unittest.case • unittest.loader • unittest.main • unittest.result • unittest.runner • unittest.signals • unittest.suite • unittest.util

imported by: doctest • test.support • test.support.testresult • unittest • unittest._log • unittest.async_case • unittest.case • unittest.loader • unittest.main • unittest.result • unittest.runner • unittest.signals • unittest.suite • unittest.util

unittest._log SourceModule

imports: collections • logging • unittest • unittest.case

imported by: unittest.case

unittest.async_case SourceModule

imports: asyncio • inspect • unittest • unittest.case

imported by: unittest

unittest.case SourceModule

imports: collections • contextlib • difflib • functools • pprint • re • sys • traceback • types • unittest • unittest._log • unittest.result • unittest.util • warnings

imported by: unittest • unittest._log • unittest.async_case • unittest.loader • unittest.suite

unittest.loader SourceModule

imports: fnmatch • functools • os • re • sys • traceback • types • unittest • unittest.case • unittest.suite • unittest.util • warnings

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

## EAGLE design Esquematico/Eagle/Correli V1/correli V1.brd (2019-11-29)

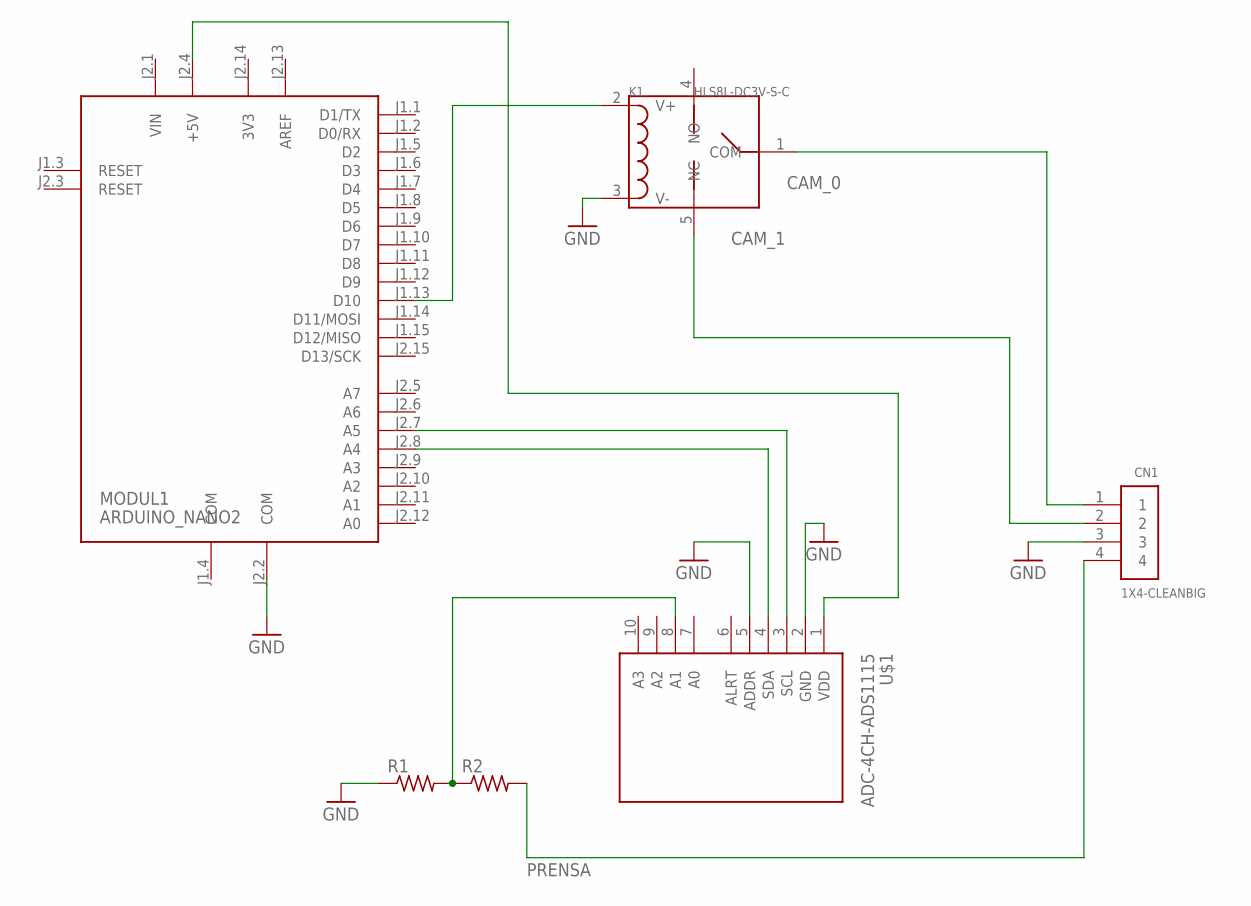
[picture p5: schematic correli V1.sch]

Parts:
CN1: 1X4-CLEANBIG; 1X04-CLEANBIG
K1: HLS8L-DC3V-S-C; REY5-19.0X15.0X15.0MM
MODUL1: ARDUINO_NANO2
R1, R2: R-US_0309/12; 0309/12
U$1: ADC-4CH-ADS1115

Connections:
3V3: MODUL1.J2.14 (3V3)
AREF: MODUL1.J2.13 (AREF)
CAM_0: CN1.1, K1.1 (COM)
CAM_1: CN1.2, K1.5 (NC)
COM: MODUL1.J1.4 (COM)
GND: CN1.3, K1.3 (V-), MODUL1.J2.2 (COM), R1.1, U$1.2 (GND), U$1.5 (ADDR)
unnamed: K1.2 (V+), MODUL1.J1.13 (D10)
unnamed: MODUL1.J2.4 (+5V), U$1.1 (VDD)
unnamed: MODUL1.J2.7 (A5), U$1.3 (SCL)
unnamed: MODUL1.J2.8 (A4), U$1.4 (SDA)
unnamed: R1.2, R2.1, U$1.8 (A1)
PRENSA: CN1.4, R2.2
VIN: MODUL1.J2.1 (VIN)

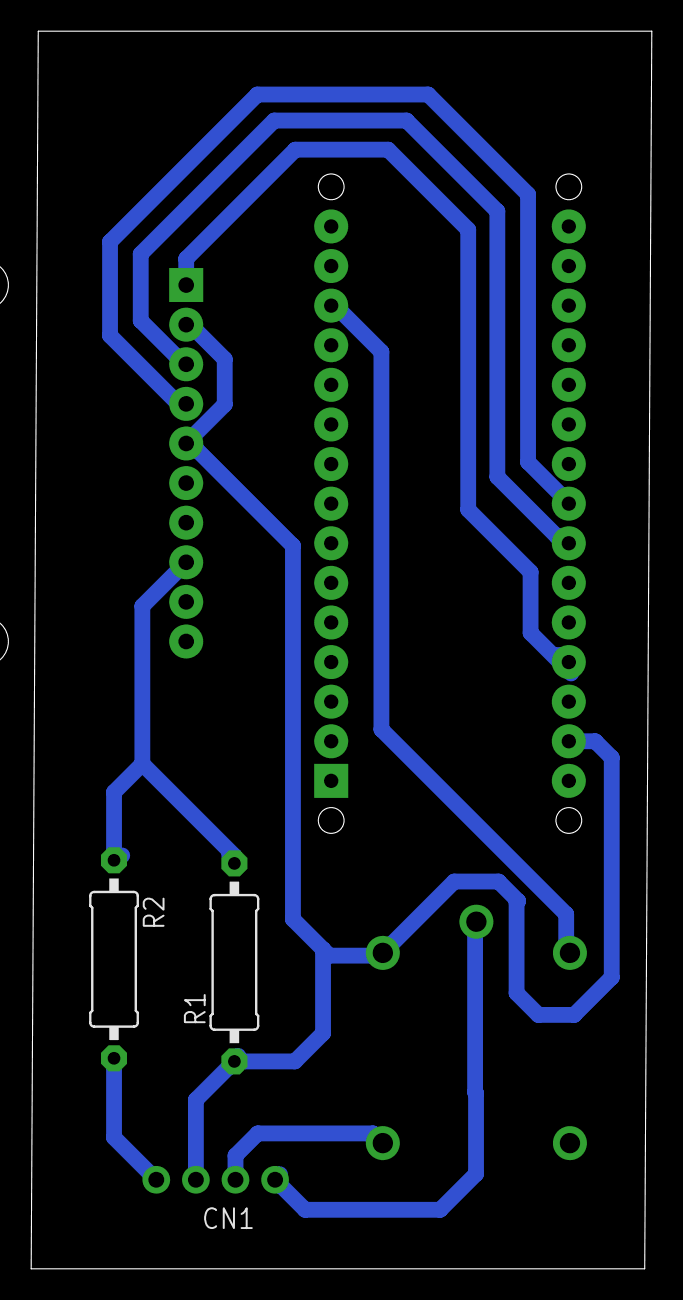
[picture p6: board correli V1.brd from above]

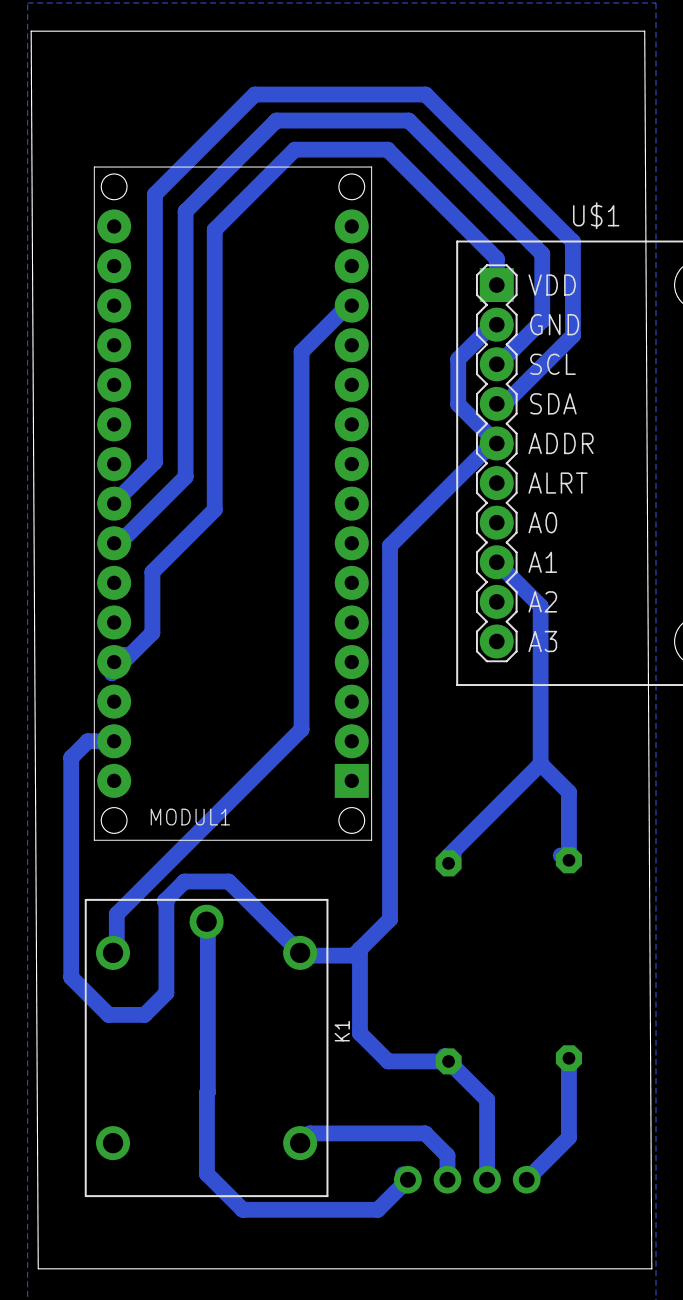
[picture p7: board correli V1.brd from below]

Board: 2 copper layers, 39.8 x 79.4 mm, 6 parts (3 on the bottom side), 9 nets.

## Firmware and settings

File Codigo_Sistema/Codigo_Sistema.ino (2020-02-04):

/*
 *         ****************  CONSIDERAÇÕES GERAIS  ****************
 * 
 * Para o funcionamento do código, é necessário instalar e importar
 * a biblioteca "Adafruit_ADS1X15.h". Ela tem o propósito de permitir a
 * comunicação entre arduino e o conversor analógico-digital (ADS1115).
 * 
 * Um detalhe importante sobre a estrutura do programa é a não utilização
 * da rotina void loop() como mantenedora dos loops do código. Optamos por
 * controlar nós mesmos os loops por meio de funções específicas, como 
 * modo_forca() e modo_tempo().
 */
  
#include <Adafruit_ADS1015.h>
#define valueModoTensao 1
#define OK 1
#define ERRO 0

float intervalo_tempo; 
float intervalo_forca;

int16_t sensorValue;
float tensaoADS;
float tensaoReal;
float tensaoAnt = 0.0;
float forca;
float forcaAnt = 0.0;

int cont = 1;
int porta_rele = 10;

unsigned long tempo;
unsigned long tempoAnt = 0;
float fundo_escala; 

/*
 * Variáveis utilizadas para auxiliar no recebimento das configurações 
 * de funcionamento do programa - dados enviados pela interface gráfica.
 */
char modo = '0';
String intervaloS = "";
String fundoS = "";
float intervalo;

/*
 * Configuração do endereço (Address) do ADS1115 como sendo o GND,
 * indicado por "0x48".
 */ 
Adafruit_ADS1115 ads(0x48);

void setup() {

  Serial.begin(9600);
  
  pinMode(porta_rele, OUTPUT);
  digitalWrite(porta_rele, HIGH);
  
  ads.begin();

  //Receber as configurações de funcionamento do programa 
  recebe_dados();
  converte_dados();

  //O programa funcionará conforme o modo acionado - força (f) ou tempo (t)
  if(modo == 'f')
  {
    Serial.println("IMAGEM       TENSAO         FORCA         FORCA_P            TENSAO_P            INTERVALO");

    intervalo_forca = intervalo;
    modo_forca();
  }
  else if(modo == 't')
  {
    Serial.println("IMAGEM       TENSAO         FORCA         FORCA_P            TENSAO_P            INTERVALO");
    intervalo_tempo = intervalo;
    modo_tempo();      
  }
}

int verificar_comecar()
{
  char verifica = '0';
  
  while(verifica == '0') //A interface deve mandar um char qualquer para comecar.
  {
    if(Serial.available()>0)
      verifica = Serial.read();       
  }

  Serial.println(verifica);
  return OK;
}

/* 
 *  Os dados enviados pela interface gráfica estão organizados em uma estrutura 
 *  fixa e muito bem definida: "modo,intervalo,fundo_de_escala", em uma única string. 
 *  Para facilitar a coleta desses dados, decidimos analisar char por char enviado
 *  pela interface e, em seguida, armazena-los em strings. 
 *  No caso do modo de operacao, havia somente duas opcoes: tempo ou forca, que foram
 *  representadas, respectivamente, por 't' e 'f'. Essa informacao foi armazenada em
 *  um unico char chamado "modo".
 *  O intervalo de operacao e o fundo de escala foram armazenados, respectivamente, nas
 *  strings "intervaloS" e "fundoS".      
 */
void recebe_dados()
{
  char caractere = '0';
  int aux_modo = OK;
  int aux_intervalo = ERRO;
  int aux_fundo = ERRO;
  int conta_virgula = 0;
  
  while(caractere != '\n')
  {
    if(Serial.available())
    {
      caractere = Serial.read();

      if(caractere == ',')
        conta_virgula++;

      if(conta_virgula == 2)
      {
        aux_intervalo = ERRO;
        aux_fundo = OK; 
      }
        
      if(caractere != ',' && aux_modo == OK && aux_intervalo == ERRO && aux_fundo == ERRO)
      {
        modo = caractere; 
        aux_modo = ERRO;
        aux_intervalo = OK;   
      }

      if(caractere != ',' && aux_modo == ERRO && aux_intervalo == OK && aux_fundo == ERRO && conta_virgula != 0)
      {
        intervaloS.concat(caractere);
      }

      if(caractere != ',' && aux_modo == ERRO && aux_intervalo == ERRO && aux_fundo == OK)
      {
        fundoS.concat(caractere);
      }
    }
  }
}

 /* 
 *  A funcao converte_dados() converte o intervalo de operacao e o fundo escala 
 * de uma string - intervaloS e fundoS - para um numero flutuante (float). 
 */
 
void converte_dados()
{
  intervalo = intervaloS.toFloat();
  fundo_escala = fundoS.toFloat();
}

/*                  Comtário sobre as funções que vêm a seguir
 * A funções modo_tempo() e modo_forca funcionam de forma análoga,conforme
 * a escolha feita pelo usuário do modo de operação do programa.
 * Essas funções são responsáveis por manter o código funcionando por tempo
 * indeterminado (loop) até que uma condição de parada (int parada) se torne
 * verdadeira, isto é, igual a 1 - isso é modificado pela rotina receber_parada().
 * Enquanto o programa funciona, as rotinas abaixo calculam a força exercida
 * pela prensa no corpo de prova por meio de calculoForca() e, conforme passa o 
 * intervalo de tempo ou de força pré determinado, acionam e desligam o relé - tarefa
 * executada por verificarTempo() ou verificarForca().
 */
 
void modo_tempo()
{
  int parada = 0;
  
  while(!parada)
  {
    calculoForca();
    verificarTempo();
    parada = receber_parada();
  }
}

void modo_forca()
{
  int parada = 0;
  
  while(!parada)
  {
    calculoForca();
    verificarForca();
    parada = receber_parada();
  }
}


void calculoForca(){
  
  sensorValue = ads.readADC_SingleEnded(1);           //Prensa conectada na porta 1
  tensaoADS = sensorValue * (0.1875 /1000);           //Ler o que vem do ADS; 0<=tensaoADS<=5V
  tensaoReal = tensaoADS*2;                           /*A tensão que vem da prensa é duas vezes 
                                                      maior que a que chega no arduino*/
  forca = map_f(sensorValue,0,65536,0,fundo_escala);

  if(forca >= fundo_escala)//Caso ocorra algum erro
      Serial.print("0");
}

void verificarForca(){

  calculoForca();

  //OBS: forcaAnt é inicializada com forcaAnt = 0.0
  //Verificamos se o intervalo de força já foi percorrido para podermos acionar o relé novamente
  if((forca - forcaAnt)>= intervalo_forca){

    Serial.print(cont);
    calculoForca();
    Serial.print("            ");
    Serial.print(tensaoReal,5);
    Serial.print("            ");
    Serial.print(forca,5); //FORCA ANTERIOR
  
    digitalWrite(porta_rele, LOW);//ACIONAMENTO DO RELE

    calculoForca();
    
    Serial.print("            ");
    Serial.print(forca,5);//FORCA POSTERIOR
    
    Serial.print("            ");
    Serial.print(tensaoReal,5); //Tensão Real
    
    Serial.print("            ");
    Serial.println(forca-forcaAnt); //Invervalo
    
    forcaAnt = forca;

    cont++;
  }else{
    digitalWrite(porta_rele, HIGH); //desliga o rele
  }
}

void verificarTempo(){
  
  tempo = millis();

  //Verificamos se o intervalo de tempo já foi percorrido para podermos acionar o relé novamente
  if((tempo - tempoAnt) >= intervalo_tempo){

    Serial.print(cont);

    calculoForca();
    Serial.print("            ");
    Serial.print(tensaoReal,4);
    Serial.print("            ");
    Serial.print(forca,4); //FORCA ANTERIOR
  
    digitalWrite(porta_rele, LOW);//ACIONAMENTO DO RELE
    Serial.print("            ");

    calculoForca();
    
  //Serial.print("            ");
    Serial.print(forca,4);//FORCA POSTERIOR
    
    Serial.print("            ");
    Serial.print(tensaoReal,4);
    
    Serial.print("            ");
    Serial.println(tempo-tempoAnt);

    tempoAnt = tempo;
    
    cont++;
    
  }else{
    digitalWrite(porta_rele, HIGH);
  }
}

/*
 * A função receber_parada() retorna 1 quando o usuário, por meio da interface,
 * indica que o programa deve parar.
 */
int receber_parada()
{
  char parada = '1';
  
  if(Serial.available()>0)
  {
    parada = Serial.read();  
  }

  if(parada == '0') //O recebimento do char '0' significa que o programa deve parar
    return 1;
  
  else
    return 0;
}

/*
 * A função map_f() é uma adapatação da função map(). Sua modificação visa permitir
 * resultados mais precisos no trabalho com números flutuantes, pois a função map() 
 * arredondava valores fracionários para inteiros.
 * Mais informações sobre a função map() no link:
 * https://www.arduino.cc/reference/pt/language/functions/math/map/
 */
float map_f(float x, float in_min, float in_max, float out_min, float out_max) {
  return (x - in_min) * (out_max - out_min) / (in_max - in_min) + out_min;
}
void loop(){}

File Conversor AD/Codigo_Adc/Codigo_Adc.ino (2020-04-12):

/*Novo código para a leitura da tensão utilizando o ADS1115
 *Bibliotecas necessárias:
 **i2cdevlib e ADS1115 disponíveis em "https://github.com/jrowberg/i2cdevlib/tree/master/Arduino"
 *Pinagem 
  ADS1115 -->  NANO
    VDD        5V
    GND        GND
    SCL        A5 (or SCL)
    SDA        A4 (or SDA)
    ALRT       2
 

*/
#include "ADS1115.h"

float tensao_millivolts;

ADS1115 adc(ADS1115_DEFAULT_ADDRESS);

//Pino do arduino que será responsavel pela alerta de leitura
const int pinoAlertReady = 2;

//Pino ligado ao relay
const int pinoRelay = 10;
int acionado;

void iniciar_ADC(){

  //inicializa o ADC
  adc.initialize();

  //seta a leitura na porta A1 com o GND como referência
  adc.setMultiplexer(ADS1115_MUX_P1_NG);

  //seta o modo single shot (um medicao por vez)
  adc.setMode(ADS1115_MODE_SINGLESHOT);

  //seta uma frequência de aquisição de 8HZ -> 125 ms
  adc.setRate(ADS1115_RATE_8);

  //Seta o ganho (PGA) +/- 6.144v (Fundo de escala)
  adc.setGain(ADS1115_PGA_6P144);

  //Habilita o pino ALERT/RDY 
  pinMode(pinoAlertReady, INPUT_PULLUP);
  adc.setConversionReadyPinMode();
  
  }

void setup() {
  //Permite a comunicação com o protocolo I2C
  Wire.begin();
  //Inicia a comunicação serial
  Serial.begin(9600);
  //Seta as configurações do ADS1115
  iniciar_ADC();
  //inicia o valor da tensão
  tensao_millivolts = 0;

  pinMode(pinoRelay,OUTPUT);
  digitalWrite(pinoRelay,LOW);
  acionado = 0;
}

void ler_ADC(){
  
  //Trigger para uma nova conversão
  adc.triggerConversion();
  
  //Espera a conversão estar feita -> pinoAlertRead = 0
  while(digitalRead(pinoAlertReady)){
    //Serial.println("=======================");
    }

  tensao_millivolts = adc.getMilliVolts(false);
 
  
  }

void loop() {
  ler_ADC();

  Serial.print("A1: "); Serial.print(tensao_millivolts,3); Serial.print("mV\n");

  if(tensao_millivolts >4000){
      if(!acionado){
        digitalWrite(pinoRelay, LOW); //aciona
        Serial.println("Acionado");
        acionado = 1;
        }
    }else{
      if(acionado){
        Serial.println("Desacionado");
        digitalWrite(pinoRelay, HIGH);
        acionado = 0;
      }
      
      }

  delay(10);
}

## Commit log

2019-05-27 Código e circuito do conversor AD adicionado
2019-05-29 Código teste de acionamento do rele por tempo
2019-05-30 Atualização no código de acionamento por tempo
2019-05-30 Criei essa pasta para ficar mais fácil de entrar no código do Arduino
2019-06-04 Pasta que contem o codigo unido de medicao por tempo e por tensao
2019-06-04 pasta com o esquemático do circuito montado
    [relé e conversor AD com potenciometros.fzz]
2019-06-07 Arrumei um erro no nome de uma das variáveis
2019-07-01 Agora a interface printa os valores obtidos pelo Arduino da prensa
2019-08-12 Interface com fundo de escala
2019-08-12 código de integraão adicionado
2019-08-27 Interface com botão de reiniciar e fechar programa
2019-09-09 Arduino recebe configuracoes
2019-09-09 Interface gráfica com conexão entre ela e o Arduino
2019-09-16 Correção de bugs
2019-09-20 Autoscroll implementado, arquivo agora armazena os valores e botão fechar funcional com arduino
2019-09-30 Interface com botão de fechar sem bug
    [interface.py]
2019-10-01 Esquemáticos do Arduino Nano adicionados
    [arduino nano.fzz]
2019-11-28 Esquematico da placa em Eagle
    [correli V1.brd, correli V1.sch]
2019-12-22 Arquivos de teste excluídos
2020-01-06 Dois arquivos da pasta Codigo_Sistema foram deletados por nao mais serem uteis para o projeto
2020-03-23 Adicionei um programa que fiz para aprender a mexer com arquivos .json
2020-03-24 Interface arrumada com janela para início de ensaio
2020-03-24 Interface com opção de local de salvamento do arquivo
2020-03-30 Interface com opção de escolha entre Arduinos e em uma única página
2020-03-30 Interface com opção de escolha entre Arduinos, em uma única página e só permitindo inserir números
2020-04-08 2 tipos de interface, uma com somente 1 página de configurações e a original
2020-04-08 2 tipos de interface, uma com somente 1 página de configurações e outra original
2020-04-11 Codigo ADC atualizado
2020-04-14 Interface sem bugs e perfeita!
    [interface_pagina_unica.py]
2020-04-15 Interface sem bugs e comentada!
    [interface_pagina_unica.py]
2020-08-17 Criacao das funcoes que salvam e carregam configuracoes json
2020-08-17 Havia esquecido de adicionar um biblioteca
2020-10-26 Bugs arrumados e usuário não pode inserir parametro vazio
    [interface_pagina_unica.py]
2020-11-25 Criacao do executavel da interface de pagina unica
2020-11-25 Corrigindo erro do ultimo commit
    [interface_pagina_unica.py]
2020-11-27 Interface sem os prints
2020-11-27 Executável add na pasta de executáveis
2021-03-15 Documentos para impressão 3D da caixa adicionados
    [parede fina.obj]

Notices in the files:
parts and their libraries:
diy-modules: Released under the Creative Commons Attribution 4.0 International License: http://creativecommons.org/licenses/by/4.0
